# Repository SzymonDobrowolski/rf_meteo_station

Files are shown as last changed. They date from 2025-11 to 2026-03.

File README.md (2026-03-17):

# 🌤️ RF Meteo Station - Custom ESP32 Weather System







A complete, end-to-end open-source weather station project. This system combines custom hardware design, 3D-printed enclosures, and an advanced multithreaded firmware architecture to deliver a modern, touch-enabled weather dashboard.

---

## 1. ⚡ PCB Design (Custom Hardware)
The hardware architecture is divided into two separate custom-designed printed circuit boards:

* **Main Indoor Unit:** Houses the ESP32 microcontroller, power management, display connector (SPI), and the nRF24L01 radio receiver.
* **External Sensor Node:** A low-power, battery-operated board featuring environmental sensors and an nRF24L01 transmitter to send data wirelessly to the main unit.

| Main Board | External Sensor Board |
|:---:|:---:|
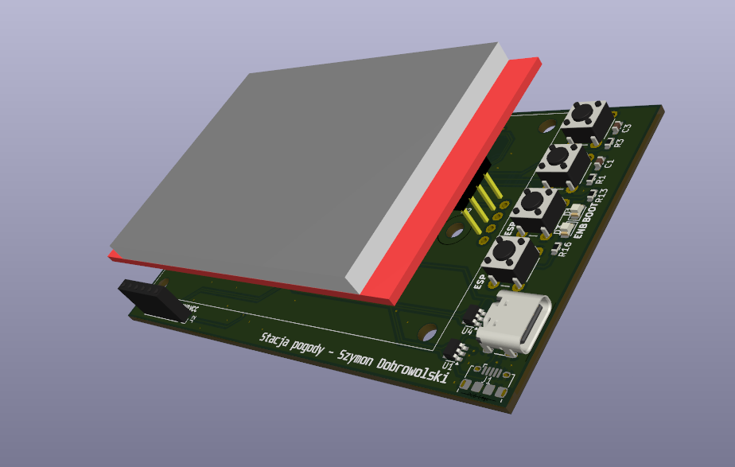
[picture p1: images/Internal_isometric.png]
Main Board PCB
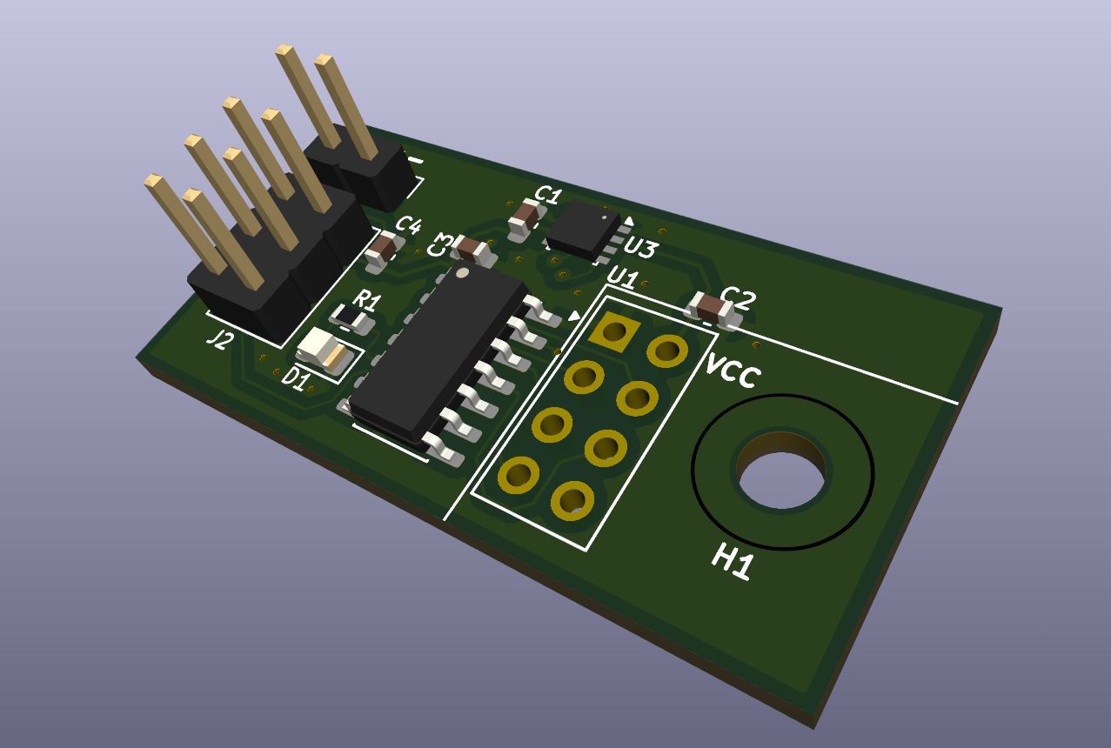
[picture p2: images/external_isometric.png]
Sensor Board PCB
|  |  |

**📄 Full Schematics (PDF):**
* [Open Main Board Schematic PDF](images/int_scheme.pdf)
* [Open Sensor Board Schematic PDF](images/ext_scheme.pdf)

---

## 2. 🧊 Enclosure Design (3D Models)
To make the project a fully finished product, custom enclosures were modeled from scratch and 3D printed.

* **Main Display Case:** Designed to perfectly fit the touch screen, custom PCB, and provide easy access to power ports.
* **Outdoor Sensor Shield:** Features a Stevenson screen-inspired design to protect the external PCB from rain and direct sunlight while allowing accurate temperature and humidity readings.

| Display Enclosure | Sensor Enclosure |
|:---:|:---:|
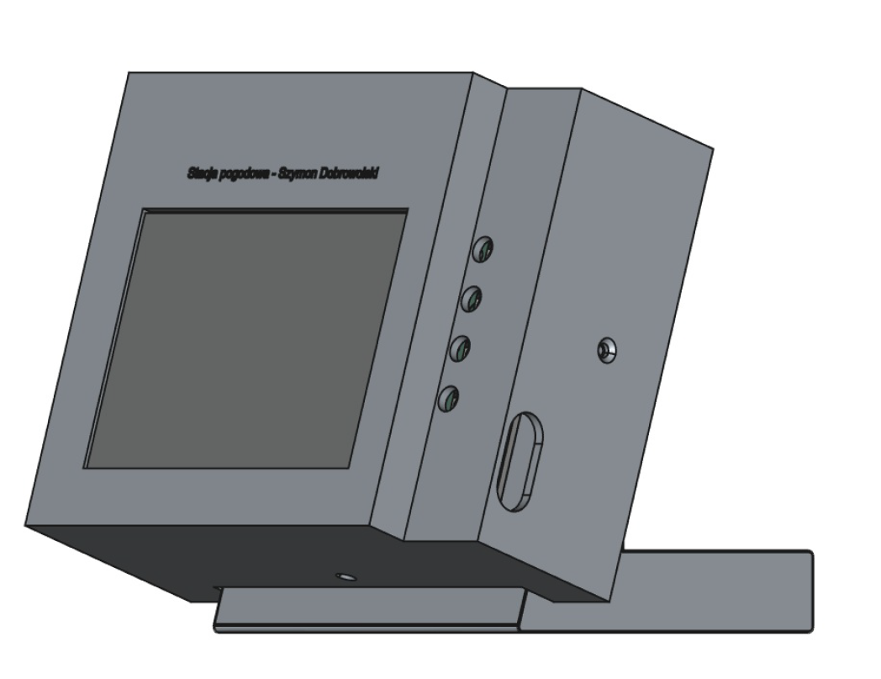
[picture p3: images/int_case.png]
Main Case 3D Model
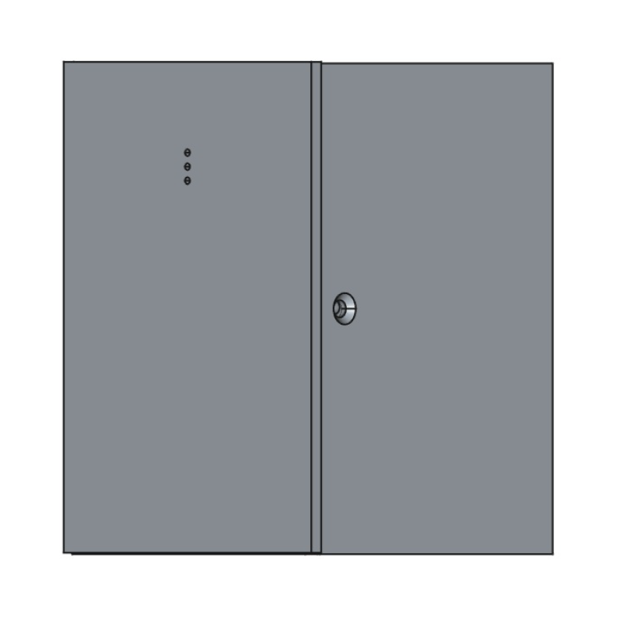
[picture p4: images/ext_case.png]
Sensor Case 3D Model
|  |  |

---

## 3. 💻 Code Architecture & Features
The firmware is built on top of the **ESP-IDF** framework and utilizes **FreeRTOS** to handle multiple background tasks without blocking the UI. 

### Key Software Features:
* **Advanced GUI (LVGL):** A fluid, touch-optimized interface featuring a dashboard, 24h interactive charts, and a 7-day forecast. The UI logic is completely decoupled from the system core.
* **Multithreading:** Dedicated FreeRTOS tasks for display rendering, wireless data receiving (nRF24L01), and Wi-Fi management.
* **Live Weather API:** Fetches and parses real-time forecast data via the Open-Meteo API using `cJSON`.
* **Smart Power Management:** Features a Day/Night mode with a PWM soft-start mechanism to prevent sudden power spikes and brownout resets.
* **NVS Storage:** Safely retains Wi-Fi credentials, location preferences, and brightness settings between reboots.
* **SNTP Time Sync:** Automatically maintains atom-accurate system time in the background.
* **Display Support:** Codebase is optimized for **ST7789** controllers with easy migration to **ILI9341** via the `esp_lcd` framework.

---

## 4. 🚀 How to Build & Flash
The software is designed for the Espressif ESP-IDF framework (v5.0 or newer).

**Step 1: Clone the repository**
```bash
git clone [https://github.com/SzymonDobrowolski/rf_meteo_station.git](https://github.com/SzymonDobrowolski/rf_meteo_station.git)
cd rf_meteo_station/ESP32_int_station_code/internal_module_code_ST7789
```

**Step 2: Install Display Dependencies (ILI9341 Only)**
*Note: The default codebase is optimized for the ST7789 controller. If your specific build uses the ILI9341 display, you must add the official driver component before building:*
```bash
idf.py add-dependency "espressif/esp_lcd_ili9341"
```

**Step 3: Build and Flash**
Connect your ESP32 board and run the following commands:
```bash
idf.py set-target esp32
idf.py build
idf.py -p (YOUR_PORT) flash monitor
```

---

## 5. 🌟 Final Result
Here is the fully assembled, programmed, and working RF Meteo Station in action!

<p align="center">
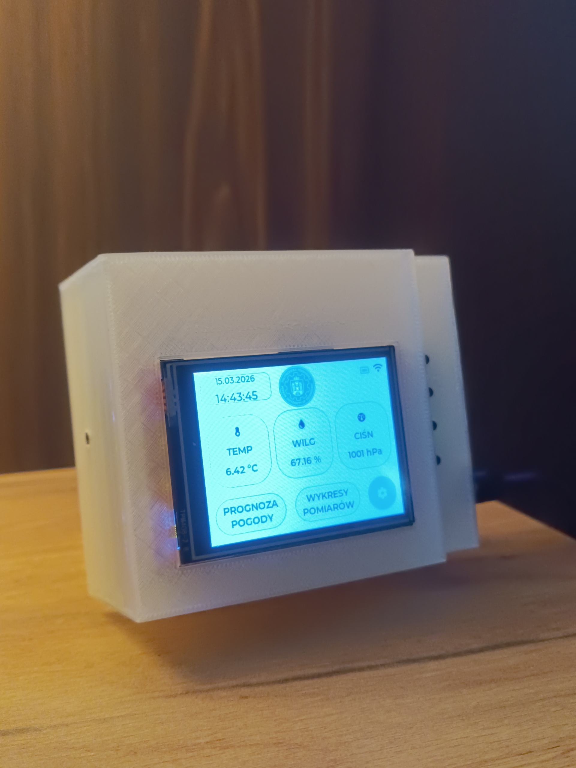
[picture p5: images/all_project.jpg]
Working Station 1
  
  &nbsp;
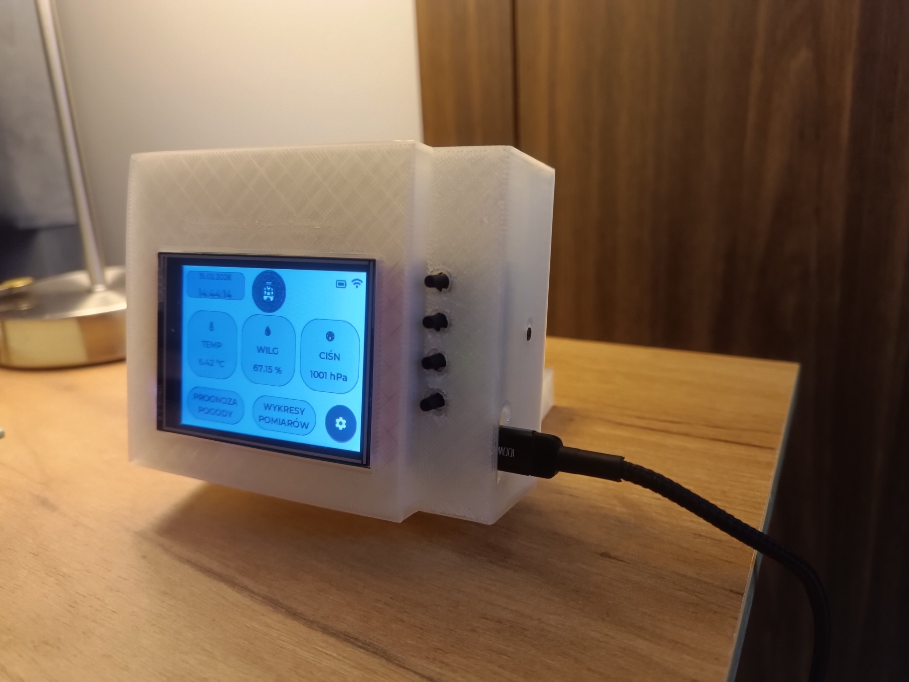
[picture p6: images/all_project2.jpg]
Working Station 2
  
</p>

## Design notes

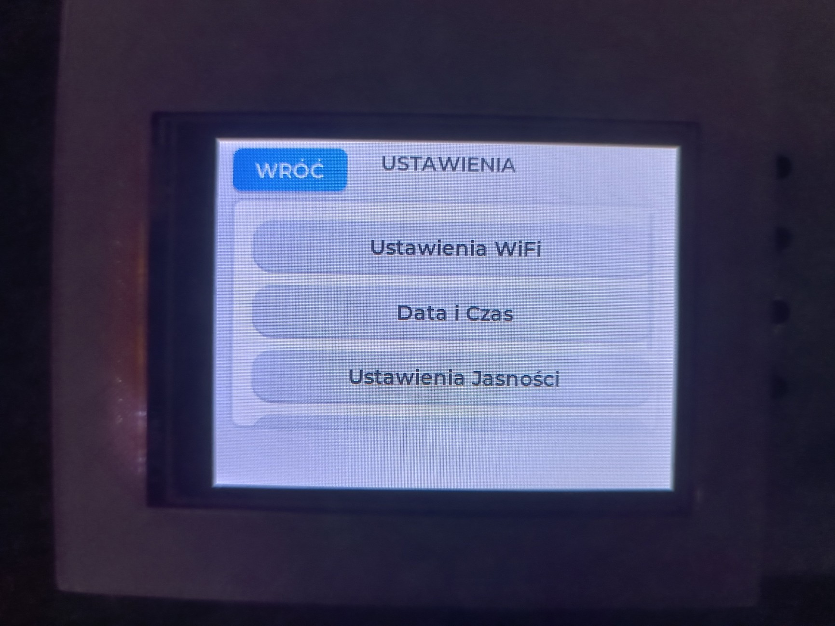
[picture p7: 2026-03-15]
images/settings_screen.jpg

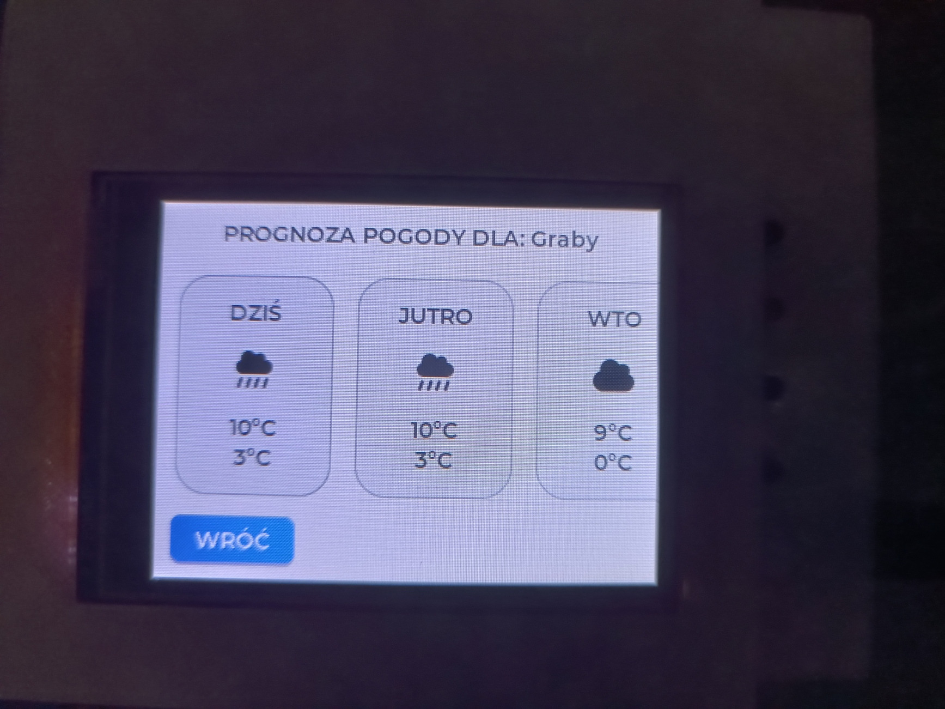
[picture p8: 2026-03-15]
images/weather_info.jpg

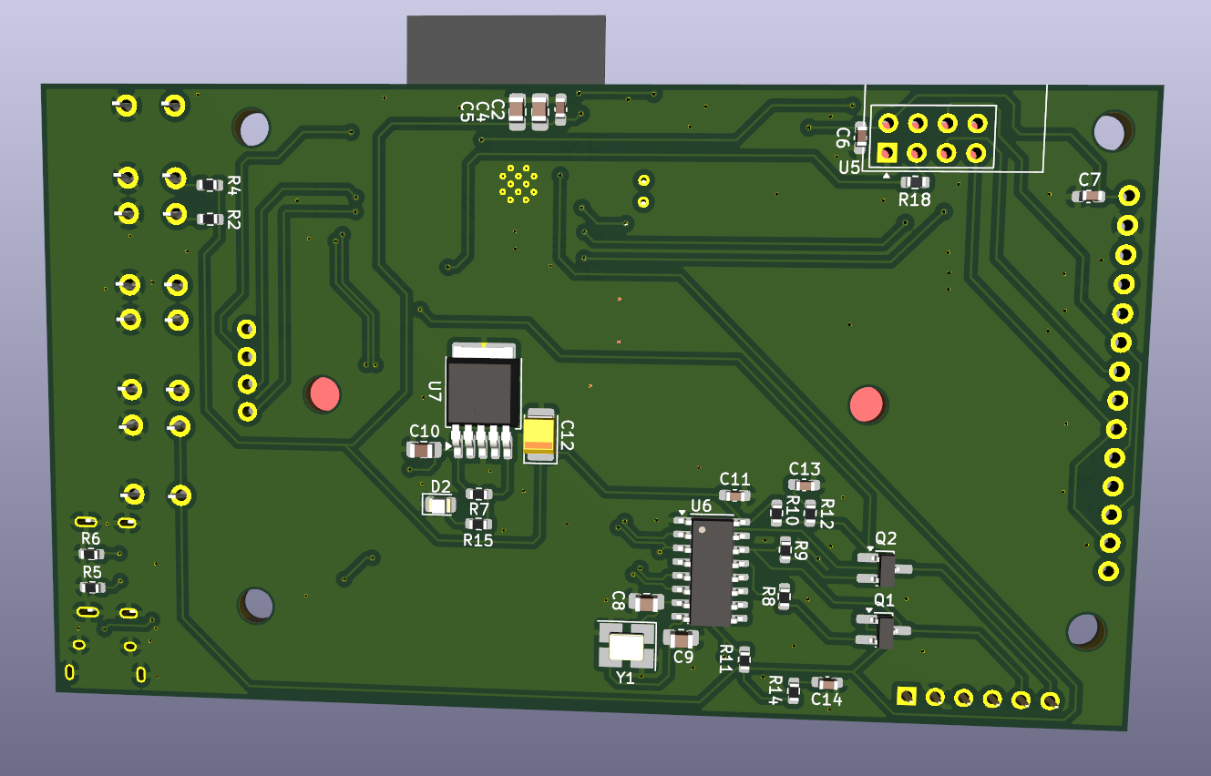
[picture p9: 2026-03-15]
images/Internal_bottom.png

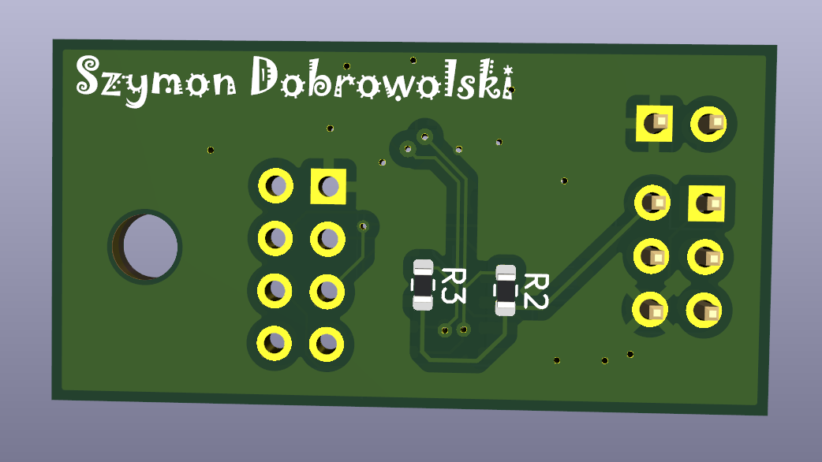
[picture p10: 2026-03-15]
images/external_bottom.png

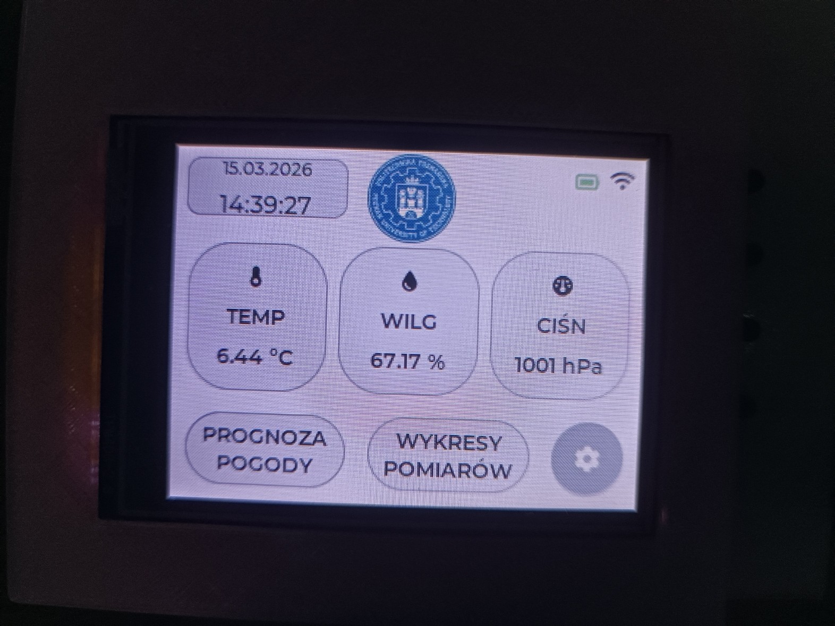
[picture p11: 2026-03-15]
images/main_screen.jpg

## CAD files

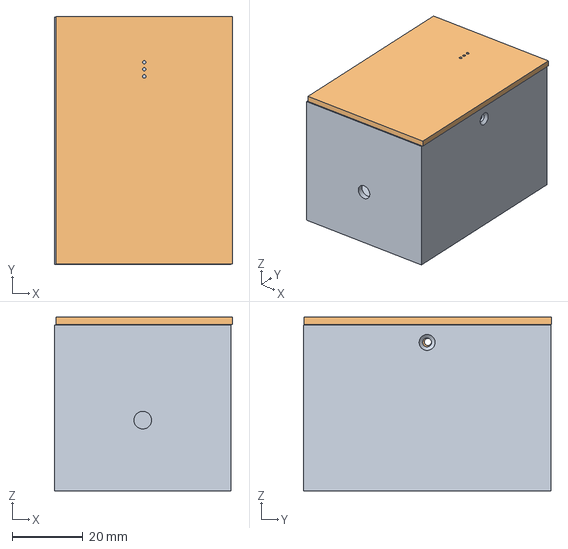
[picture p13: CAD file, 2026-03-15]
ext_station_case/case_ext_merged.FCStd
50.4 x 70.2 x 49.1 mm
Case_ext_001
Case_ext_top_001

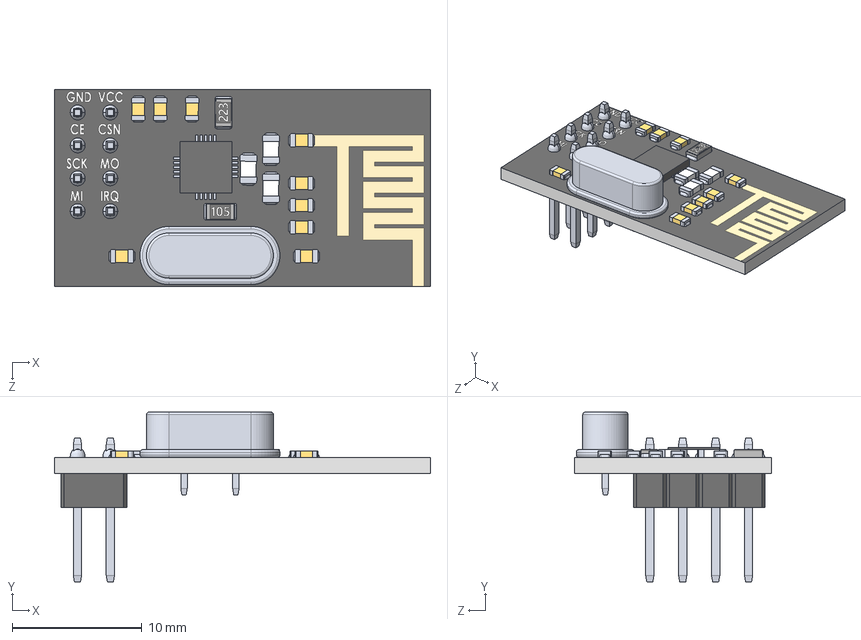
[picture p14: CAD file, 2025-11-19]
ext_station_pcb/wireless-radio-transmitter-and-receiver-nrf24l01-1.snapshot.5/Wireless Radio Transmitter and Receiver nRF24L01.STEP
29.0 x 13.1 x 15.2 mm
nrfboard
CrystalOscillator
doubleMaleHeader x 4
solder x 8
1.7mmSmdCeramicCapacitor x 9
smdResistor223
smdResistor105
smdceramiccapacitorwhite x 3
4x4SMDchip

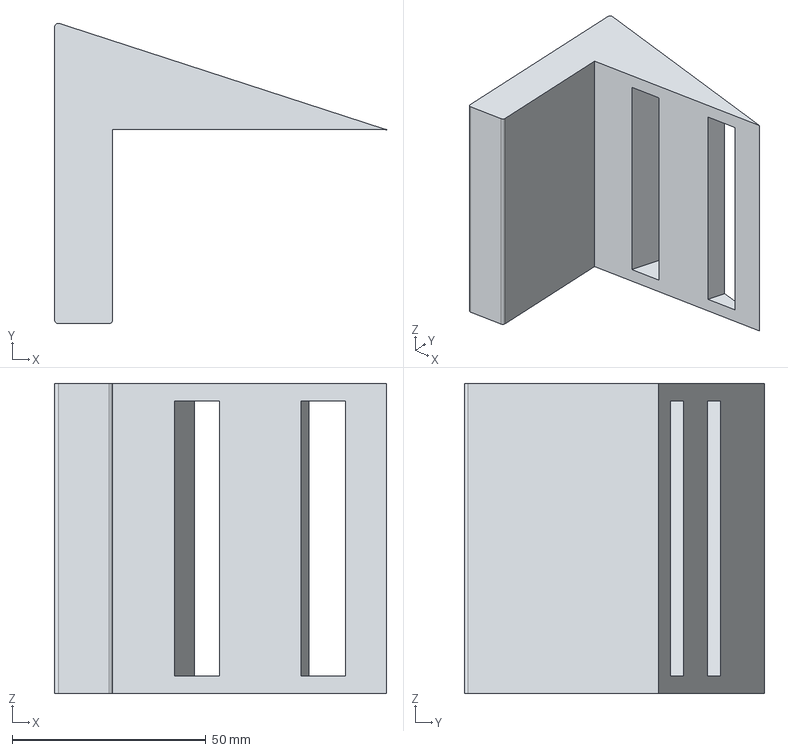
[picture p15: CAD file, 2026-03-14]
int_station_case/Mount-MountPocket002.step
85.6 x 77.4 x 80.0 mm

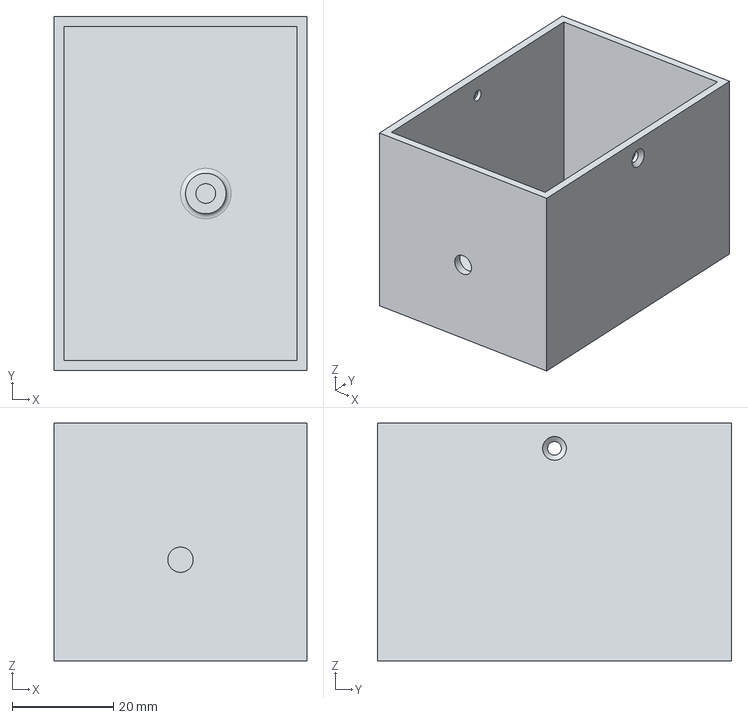
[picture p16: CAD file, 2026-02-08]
ext_station_case/Case_ext.step
50.0 x 70.0 x 47.0 mm

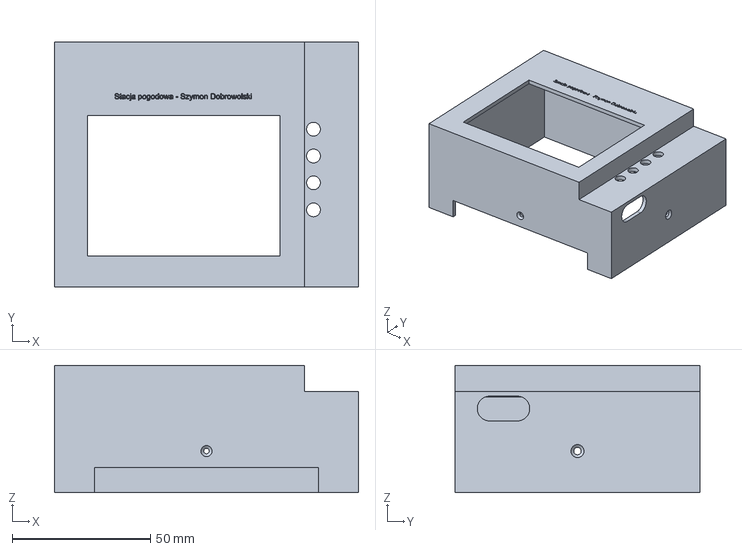
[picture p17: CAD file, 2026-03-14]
int_station_case/Internal_station_top_case.FCStd
110.1 x 88.6 x 46.0 mm

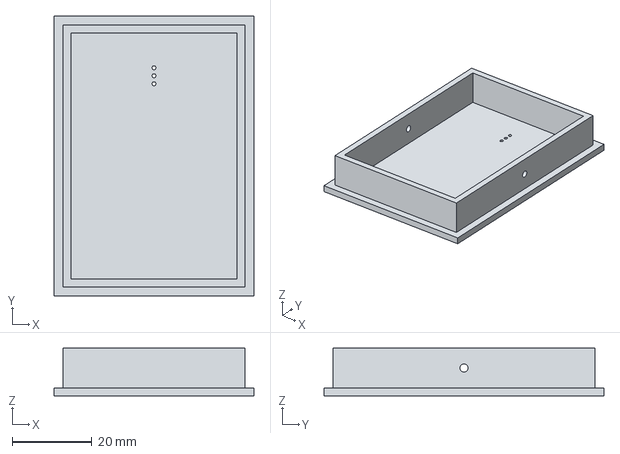
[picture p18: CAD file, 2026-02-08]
ext_station_case/Case_ext_top.step
50.0 x 70.0 x 12.0 mm

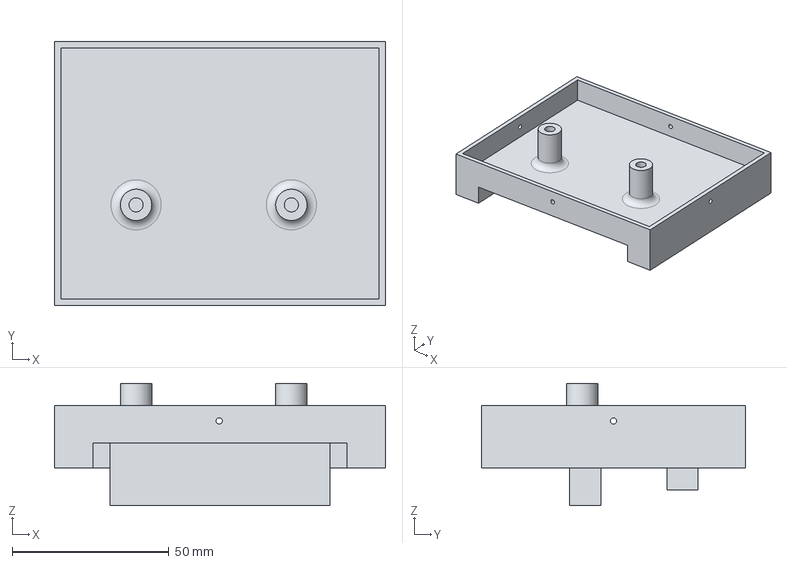
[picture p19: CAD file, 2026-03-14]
int_station_case/Interial_station_bottom_case-BodyHole001.step
105.5 x 84.0 x 39.0 mm

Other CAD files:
int_station_case/Interial_station_bottom_case.FCStd
int_station_case/Mount.FCStd
int_station_case/Internal_station_top_case-BodyHole006.step
ext_station_case/Case_ext.3mf
ext_station_case/Case_ext.FCStd
ext_station_case/Case_ext.stl
ext_station_case/Case_ext_top.3mf
ext_station_case/Case_ext_top.FCStd
ext_station_case/Case_ext_top.stl
ext_station_pcb/wireless-radio-transmitter-and-receiver-nrf24l01-1.snapshot.5/Wireless Radio Transmitter and Receiver nRF24L01.x_t
int_station_case/Interial_station_bottom_case.stl
int_station_case/Internal_station_top_case.stl
int_station_case/Mount.stl

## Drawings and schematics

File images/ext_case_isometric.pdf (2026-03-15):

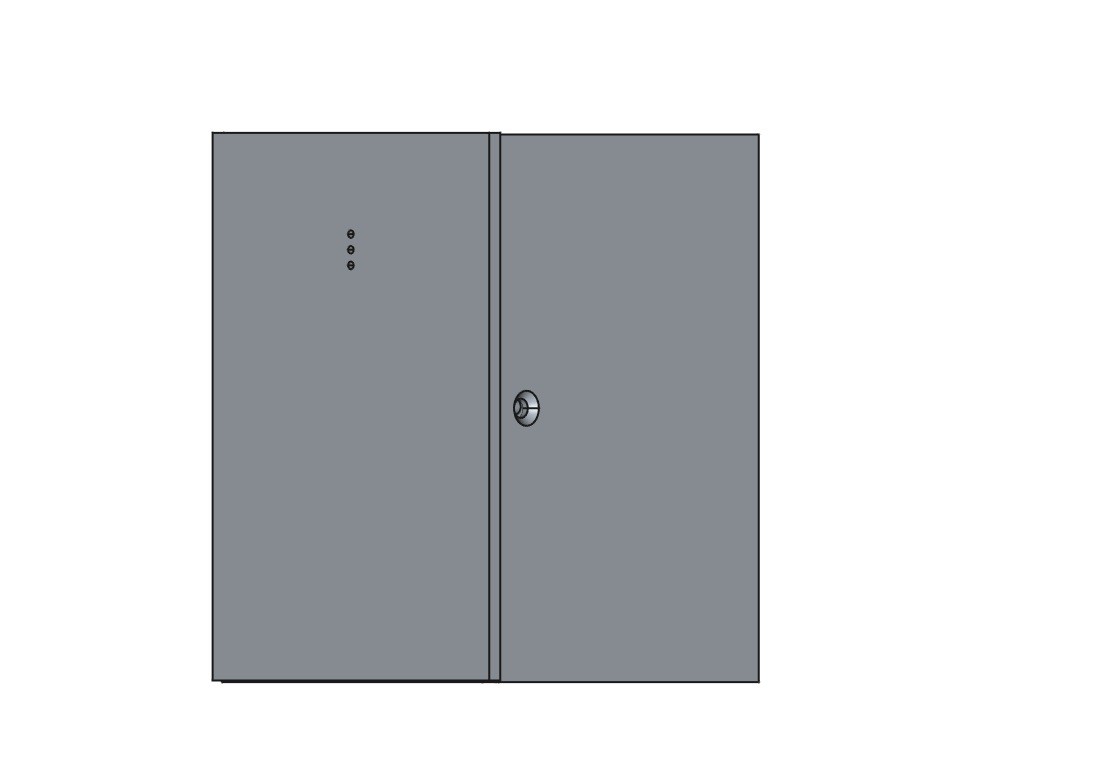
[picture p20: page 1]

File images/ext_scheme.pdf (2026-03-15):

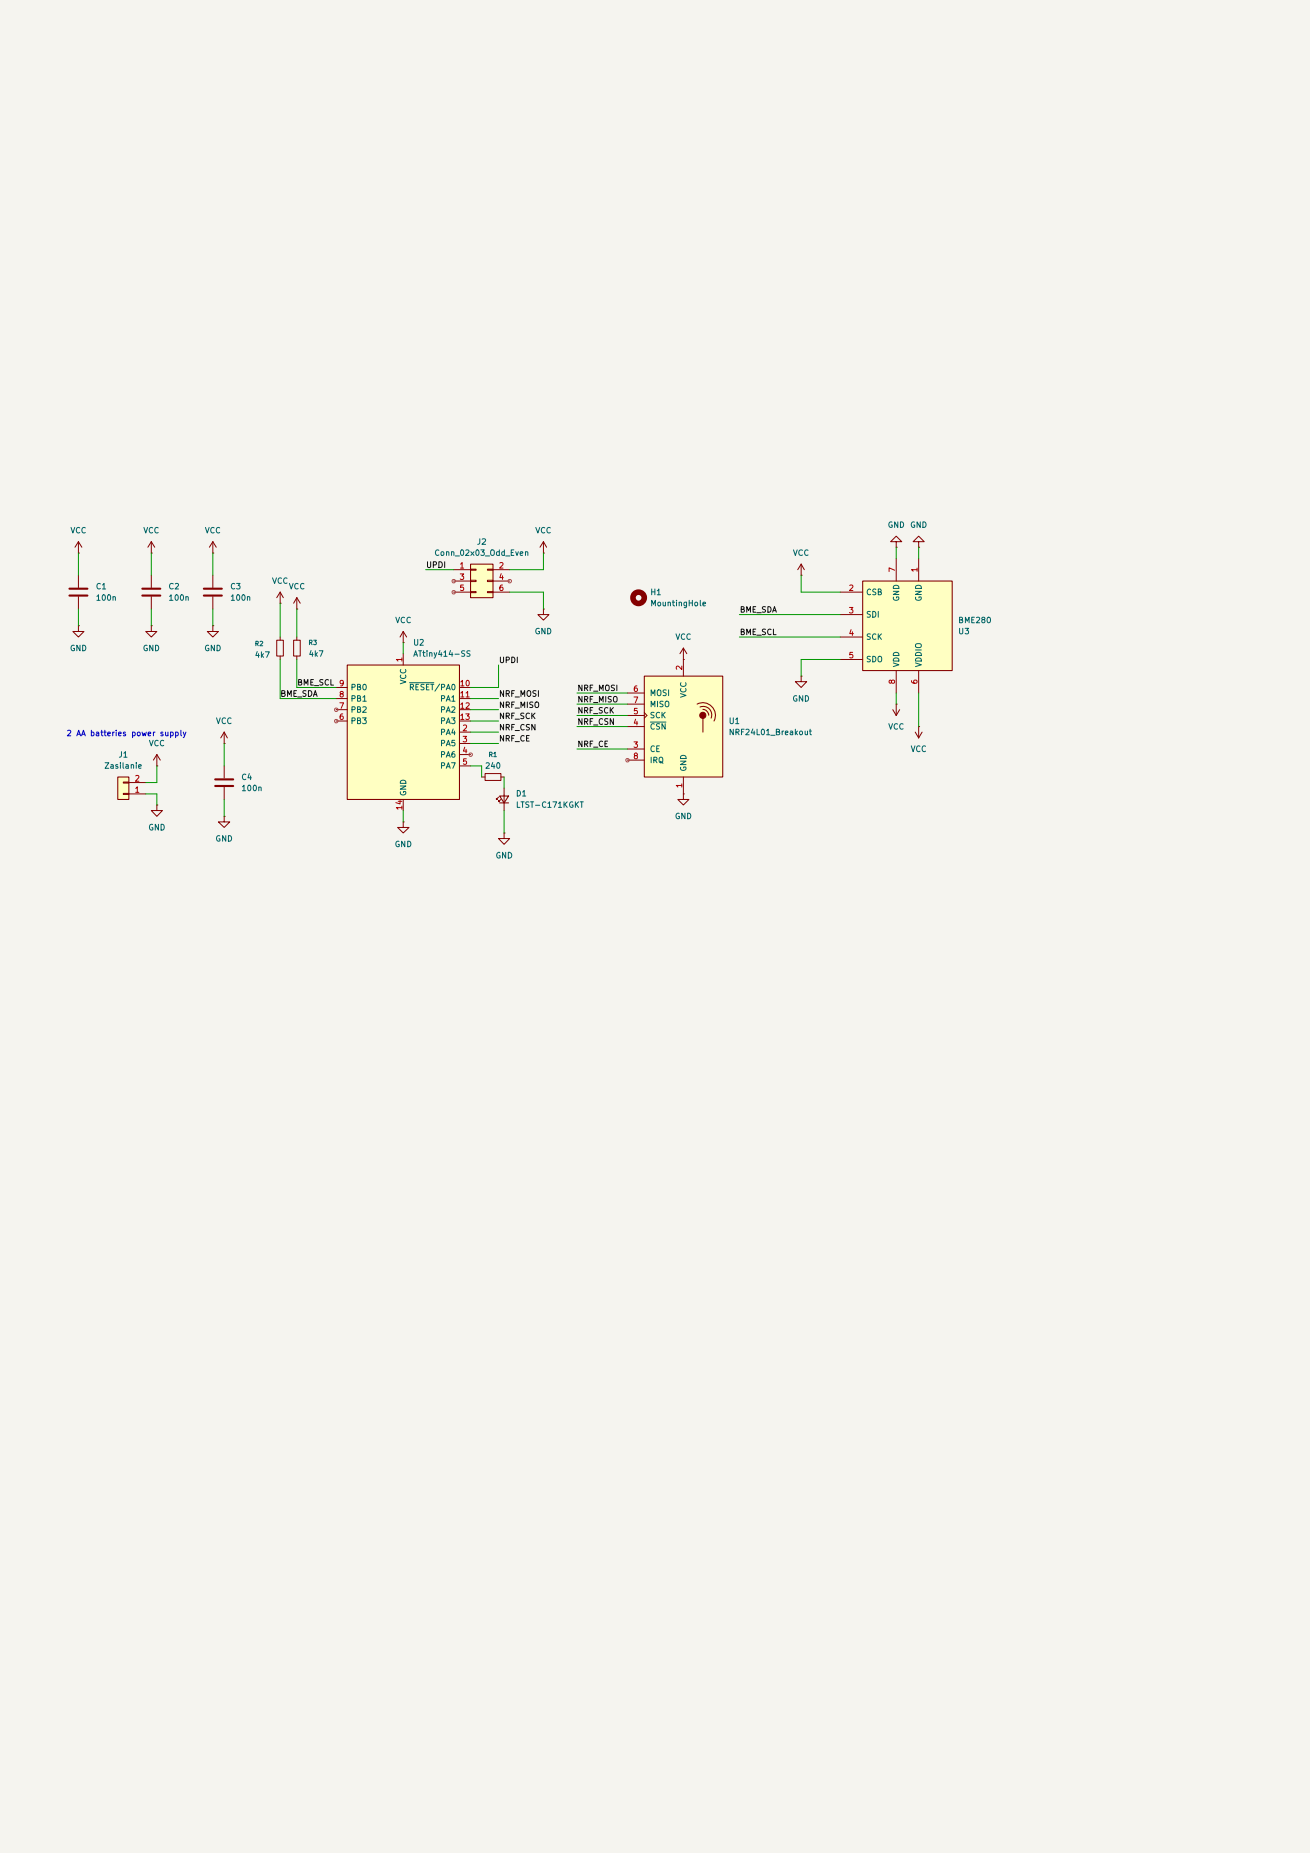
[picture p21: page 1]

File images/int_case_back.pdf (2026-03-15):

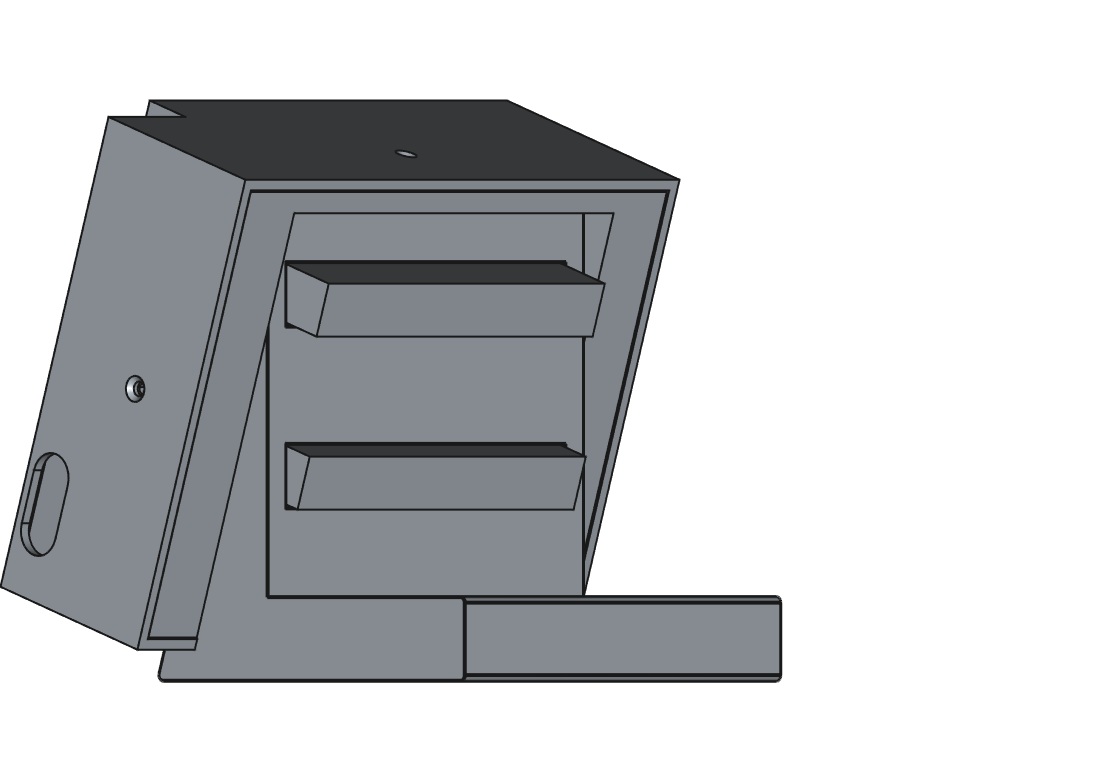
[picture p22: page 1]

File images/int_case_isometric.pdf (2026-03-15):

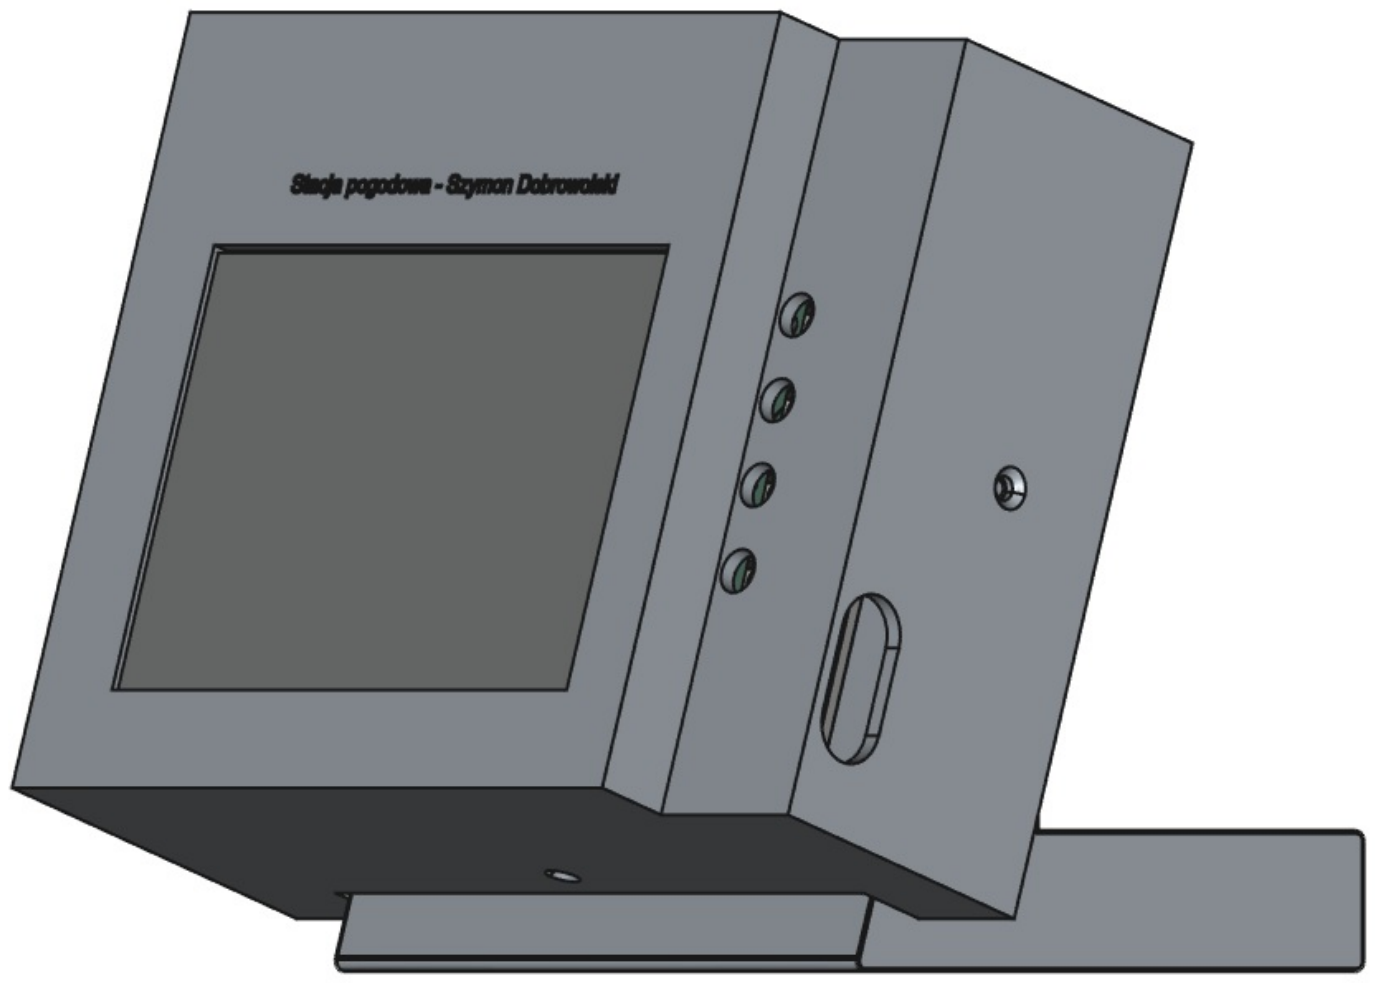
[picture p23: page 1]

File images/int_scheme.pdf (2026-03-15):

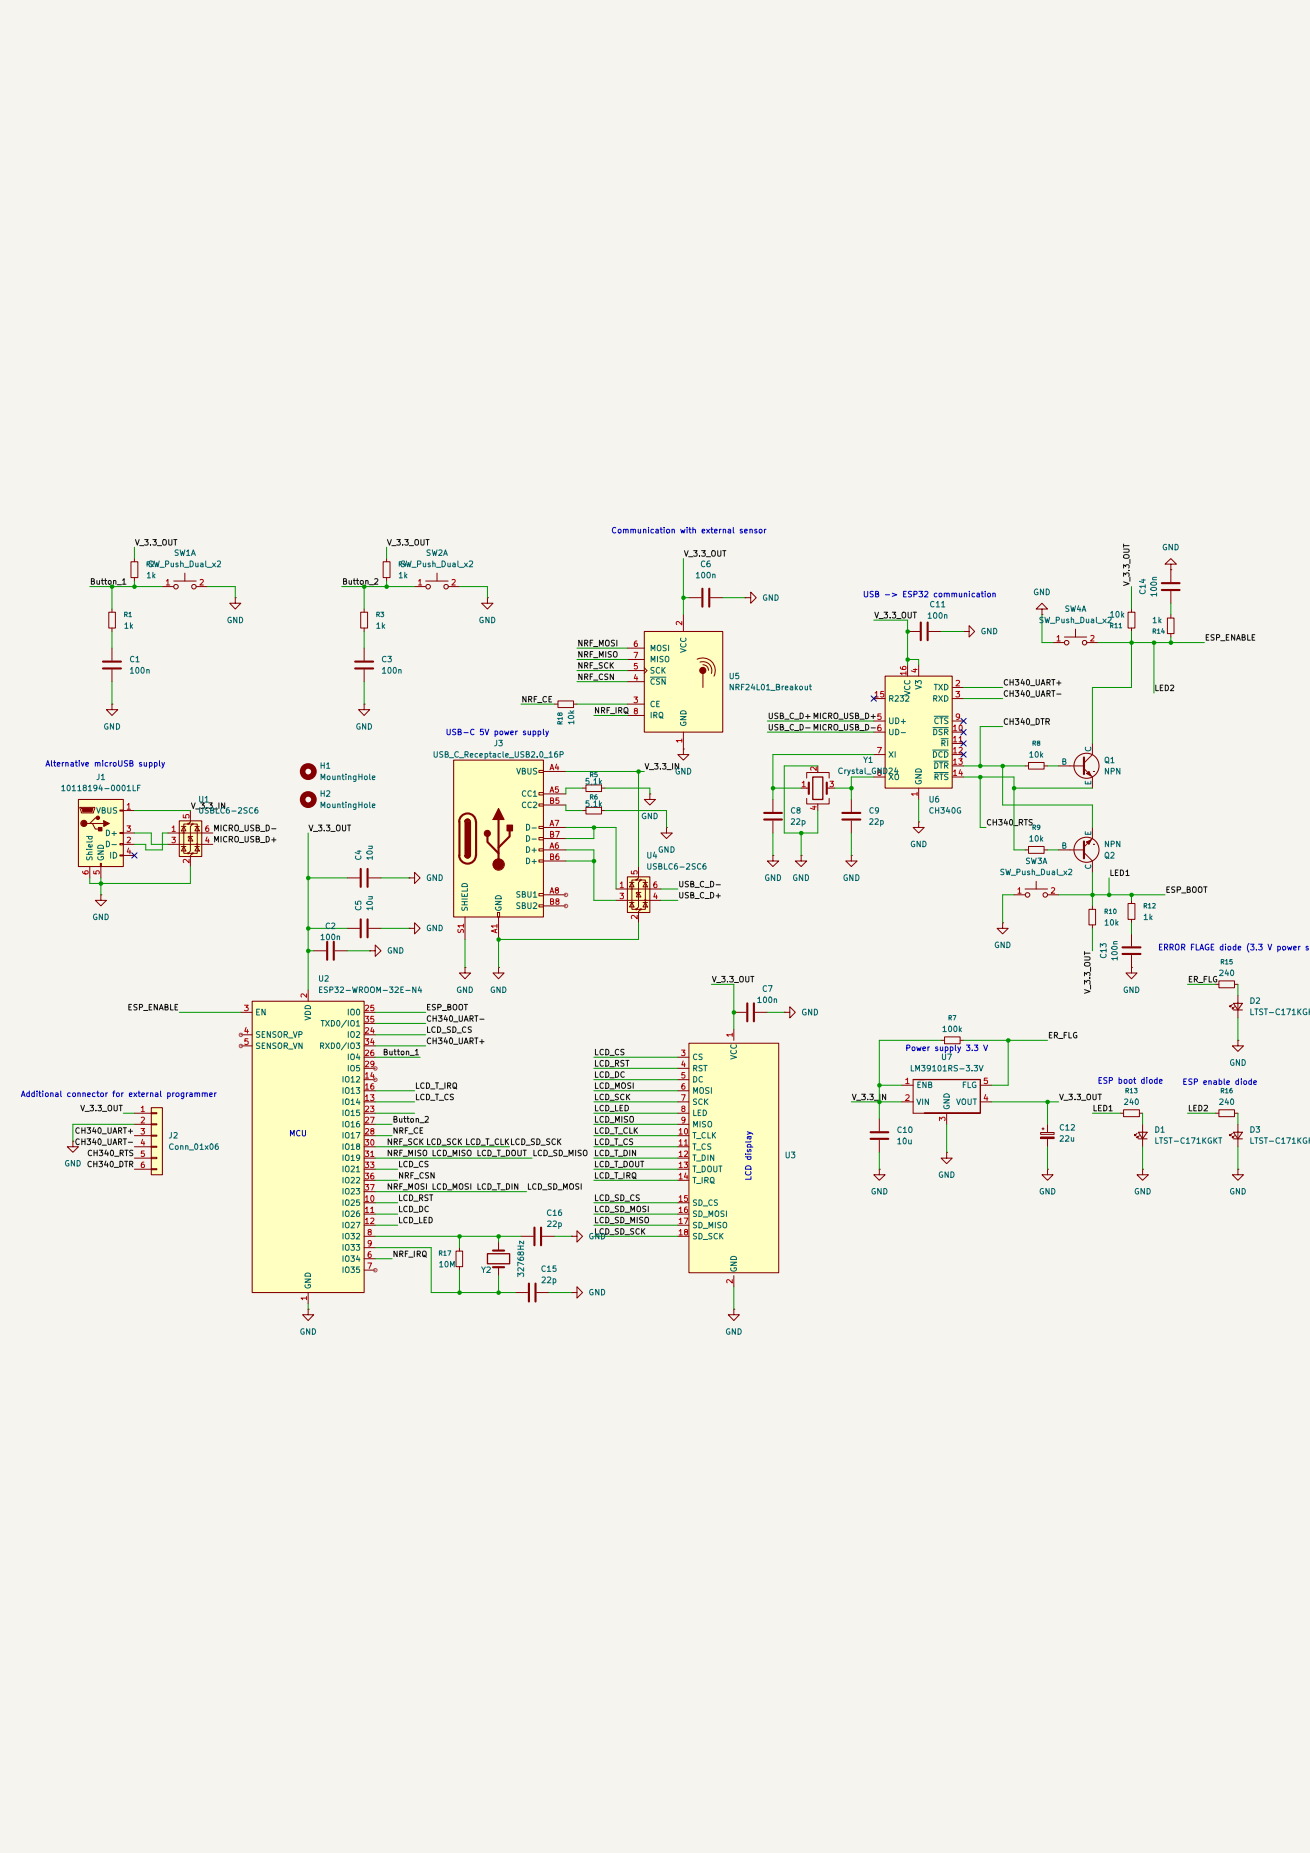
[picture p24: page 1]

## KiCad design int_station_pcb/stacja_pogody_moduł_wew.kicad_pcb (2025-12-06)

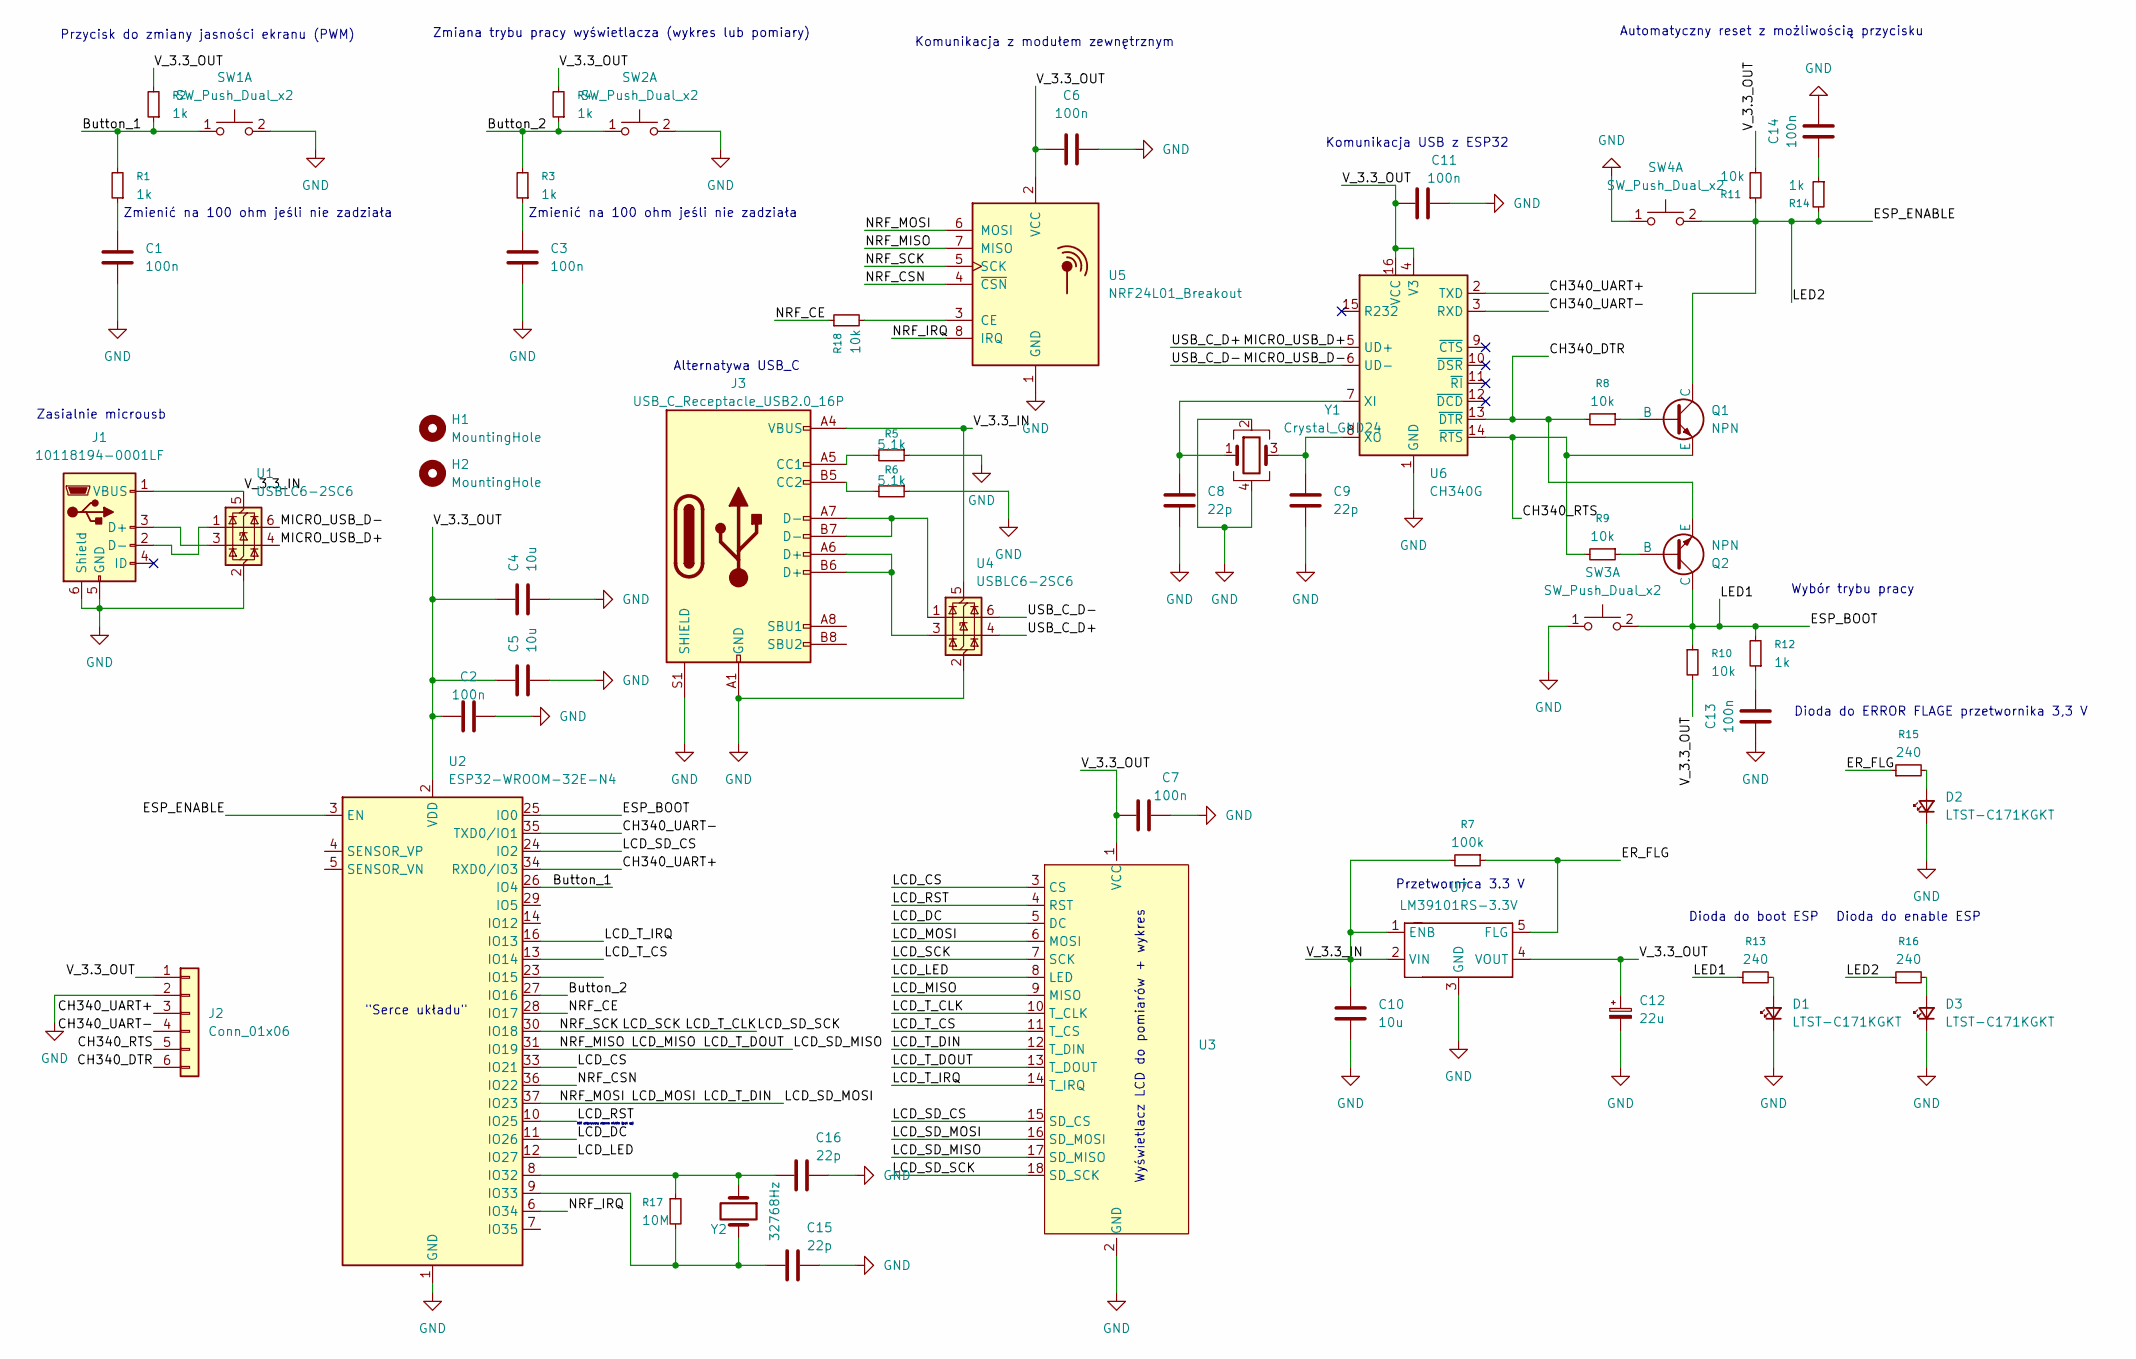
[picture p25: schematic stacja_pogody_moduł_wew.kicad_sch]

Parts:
C1, C2, C3, C6, C7, C11, C13, C14: 100n; C_0603_1608Metric_Pad1.08x0.95mm_HandSolder
C4, C5, C10: 10u; C_0805_2012Metric_Pad1.18x1.45mm_HandSolder
C8, C9: 22p; C_0805_2012Metric_Pad1.18x1.45mm_HandSolder
C12: 22u; CP_EIA-3528-21_Kemet-B_HandSolder
C15, C16: 22p; C_0603_1608Metric_Pad1.08x0.95mm_HandSolder
D1, D2, D3: LTST-C171KGKT; LED_0805_2012Metric
H1, H2: MountingHole; MountingHole_3.2mm_M3
J1: 10118194-0001LF; USB_Micro-B_Amphenol_10118194-0001LF_Horizontal
J2: Conn_01x06; PinSocket_1x06_P2.54mm_Vertical
J3: USB_C_Receptacle_USB2.0_16P; USB_C_Receptacle_TME
Q1, Q2: NPN; SOT-23_Handsoldering
R1, R2, R3, R4, R12, R14: 1k; R_0603_1608Metric
R5, R6: 5,1k; R_0603_1608Metric
R7: 100k; R_0603_1608Metric
R8, R9, R10, R11, R18: 10k; R_0603_1608Metric
R13, R15, R16: 240; R_0603_1608Metric
R17: 10M; R_0603_1608Metric
SW1, SW2, SW3, SW4: SW_Push_Dual_x2; SW_PUSH_6mm_H4.3mm
U1, U4: USBLC6-2SC6; SOT-23-6
U2: ESP32-WROOM-32E-N4; ESP32-WROOM-32E
U3: LCD_2_8
U5: NRF24L01_Breakout; nRF24L01_Breakout
U6: CH340G; SOIC-16_3.9x9.9mm_P1.27mm
U7: LM39101RS-3.3V; TO-252-5_TabPin3
Y1: Crystal_GND24; Crystal_SMD_3225-4Pin_3.2x2.5mm_HandSoldering
Y2: 32768Hz; Crystal_DS26_D2.0mm_L6.0mm_Horizontal

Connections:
/Button_1: R1.2, R2.1, SW1.1 (C), U2.26 (IO4)
/Button_2: R3.2, R4.1, SW2.1 (C), U2.27 (IO16)
/CH340_DTR: J2.6, Q2.3 (E), R8.2, U6.13 (~DTR)
/CH340_RTS: J2.5, Q1.3 (E), R9.2, U6.14 (~RTS)
/CH340_UART+: J2.3, U2.34 (RXD0/IO3), U6.2 (TXD)
/CH340_UART-: J2.4, U2.35 (TXD0/IO1), U6.3 (RXD)
/ER_FLG: R7.1, R15.1, U7.5 (FLG)
/ESP_BOOT: Q2.1 (C), R10.1, R12.2, R13.1, SW3.2 (D), U2.25 (IO0)
/ESP_ENABLE: Q1.1 (C), R11.1, R14.2, R16.1, SW4.2 (D), U2.3 (EN)
/LCD_CS: U2.33 (IO21), U3.3 (CS)
/LCD_DC: U2.11 (IO26), U3.5 (DC)
/LCD_LED: U2.12 (IO27), U3.8 (LED)
/LCD_MISO: U2.31 (IO19), U3.9 (MISO), U3.13 (T_DOUT), U3.17 (SD_MISO), U5.7 (MISO)
/LCD_MOSI: U2.37 (IO23), U3.6 (MOSI), U3.12 (T_DIN), U3.16 (SD_MOSI), U5.6 (MOSI)
/LCD_RST: U2.10 (IO25), U3.4 (RST)
/LCD_SCK: U2.30 (IO18), U3.7 (SCK), U3.10 (T_CLK), U3.18 (SD_SCK), U5.5 (SCK)
/LCD_SD_CS: U2.24 (IO2), U3.15 (SD_CS)
/LCD_T_CS: U2.13 (IO14), U3.11 (T_CS)
/LCD_T_IRQ: U2.16 (IO13), U3.14 (T_IRQ)
/MICRO_USB_D+: U1.4 (I/O2), U4.4 (I/O2), U6.5 (UD+)
/MICRO_USB_D-: U1.6 (I/O1), U4.6 (I/O1), U6.6 (UD-)
/NRF_CE: R18.1, U2.28 (IO17)
/NRF_CSN: U2.36 (IO22), U5.4 (~CSN)
/NRF_IRQ: U2.6 (IO34), U5.8 (IRQ)
/V_3.3_IN: C10.2, J1.1 (VBUS), J3.A4 (VBUS), J3.A9 (VBUS), J3.B4 (VBUS), J3.B9 (VBUS), R7.2, U1.5 (VBUS), U4.5 (VBUS), U7.1 (ENB), U7.2 (VIN)
/V_3.3_OUT: C2.2, C4.2, C5.2, C6.2, C7.2, C11.2, C12.1, J2.1, R2.2, R4.2, R10.2, R11.2, U2.2 (VDD), U3.1 (VCC), U5.2 (VCC), U6.4 (V3), U6.16 (VCC), U7.4 (VOUT)
GND: C1.1, C2.1, C3.1, C4.1, C5.1, C6.1, C7.1, C8.2, C9.2, C10.1, C11.1, C12.2, C13.2, C14.2, C15.1, C16.1, D1.1 (K), D2.1 (K), D3.1 (K), J1.5 (GND), J1.6 (Shield), J2.2, J3.A1 (GND), J3.A12 (GND), J3.B1 (GND), J3.B12 (GND), J3.S1 (SHIELD), R5.1, R6.1, SW1.2 (D), SW2.2 (D), SW3.1 (C), SW4.1 (C), U1.2 (GND), U2.1 (GND), U2.15 (GND), U2.38 (GND), U2.39 (GND), U3.2 (GND), U4.2 (GND), U5.1 (GND), U6.1 (GND), U7.3 (GND), Y1.2, Y1.4
unnamed: C1.2, R1.1
unnamed: C3.2, R3.1
unnamed: C13.1, R12.1
unnamed: C14.1, R14.1
unnamed: D1.2 (A), R13.2
unnamed: D2.2 (A), R15.2
unnamed: D3.2 (A), R16.2
unnamed: J1.3 (D+), U1.3 (I/O2)
unnamed: J1.2 (D-), U1.1 (I/O1)
unnamed: J3.A5 (CC1), R5.2
unnamed: J3.B5 (CC2), R6.2
unnamed: J3.A6 (D+), J3.B6 (D+), U4.3 (I/O2)
unnamed: J3.A7 (D-), J3.B7 (D-), U4.1 (I/O1)
unnamed: Q1.2 (B), R8.1
unnamed: Q2.2 (B), R9.1
unnamed: C16.2, R17.1, U2.8 (IO32), Y2.1
unnamed: C15.2, R17.2, U2.9 (IO33), Y2.2
unnamed: R18.2, U5.3 (CE)
unnamed: C8.1, U6.7 (XI), Y1.1
unnamed: C9.1, U6.8 (XO), Y1.3

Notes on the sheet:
Wyświetlacz LCD do pomiarów + wykres
Komunikacja z modułem zewnętrznym
Zmienić na 100 ohm jeśli nie zadziała
Zasialnie microusb
Wybór trybu pracy
Dioda do enable ESP
Automatyczny reset z możliwością przycisku
Dioda do boot ESP
RST aktywowany stanem niskim (pull up)
Alternatywa USB_C
Dioda do ERROR FLAGE przetwornika 3,3 V
Komunikacja USB z ESP32
Zmiana trybu pracy wyświetlacza (wykres lub pomiary)
Przycisk do zmiany jasności ekranu (PWM)
"Serce układu"
Przetwornica 3.3 V

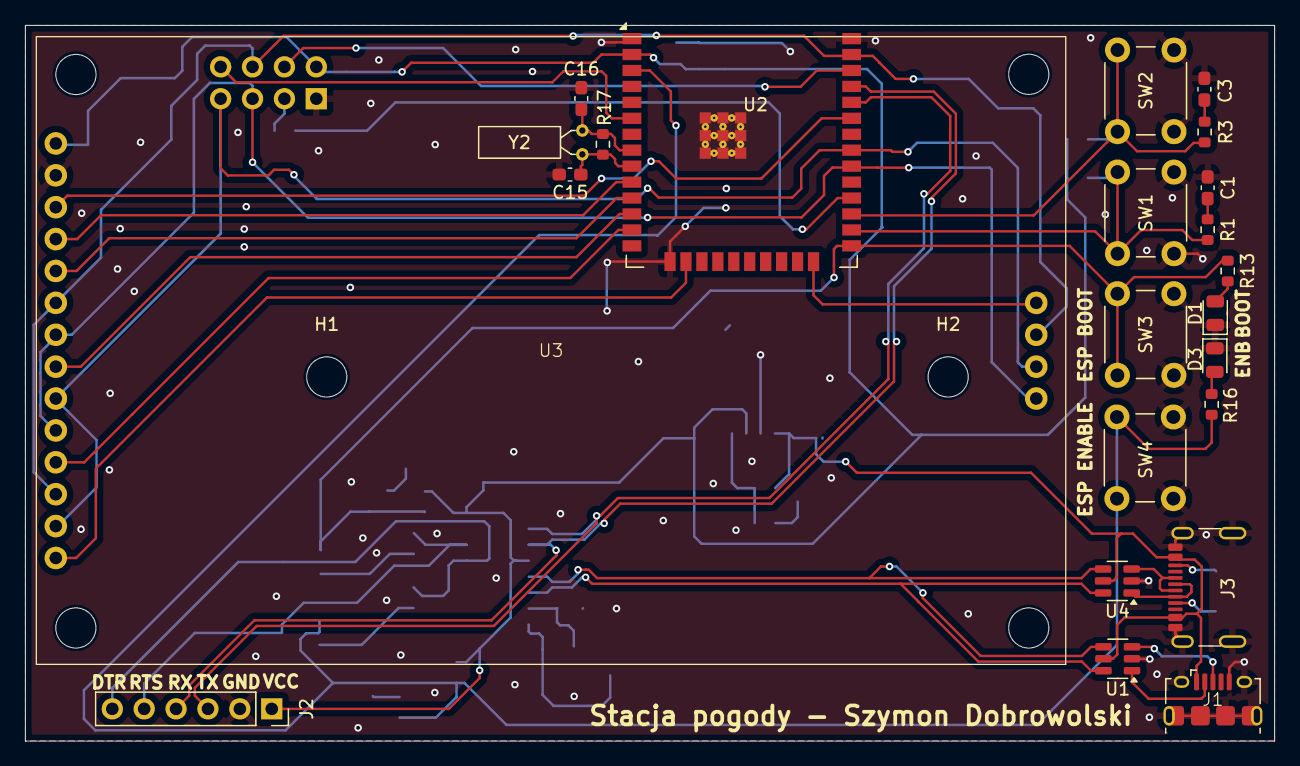
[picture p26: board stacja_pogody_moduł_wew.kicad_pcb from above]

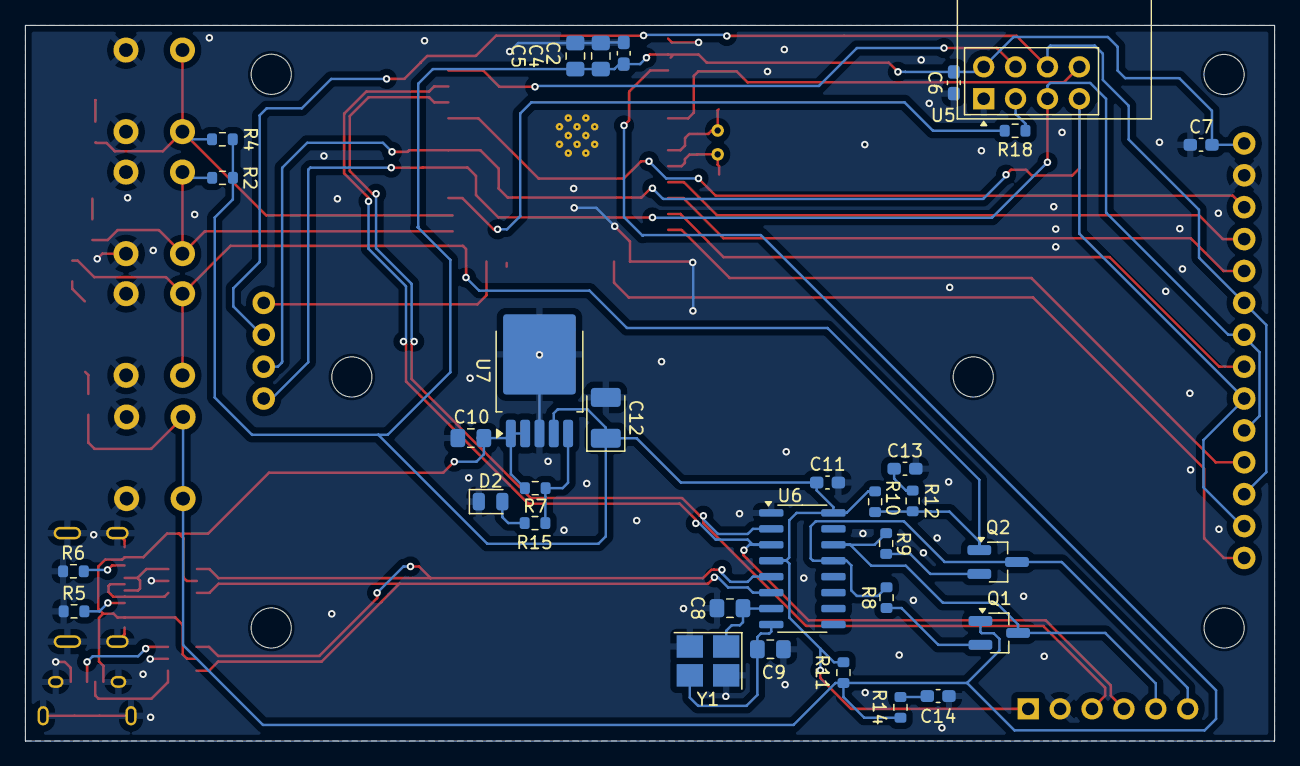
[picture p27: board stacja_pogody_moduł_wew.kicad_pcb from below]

Board: 2 copper layers, 99.5 x 57.0 mm, 57 parts (32 on the bottom side), 47 nets.

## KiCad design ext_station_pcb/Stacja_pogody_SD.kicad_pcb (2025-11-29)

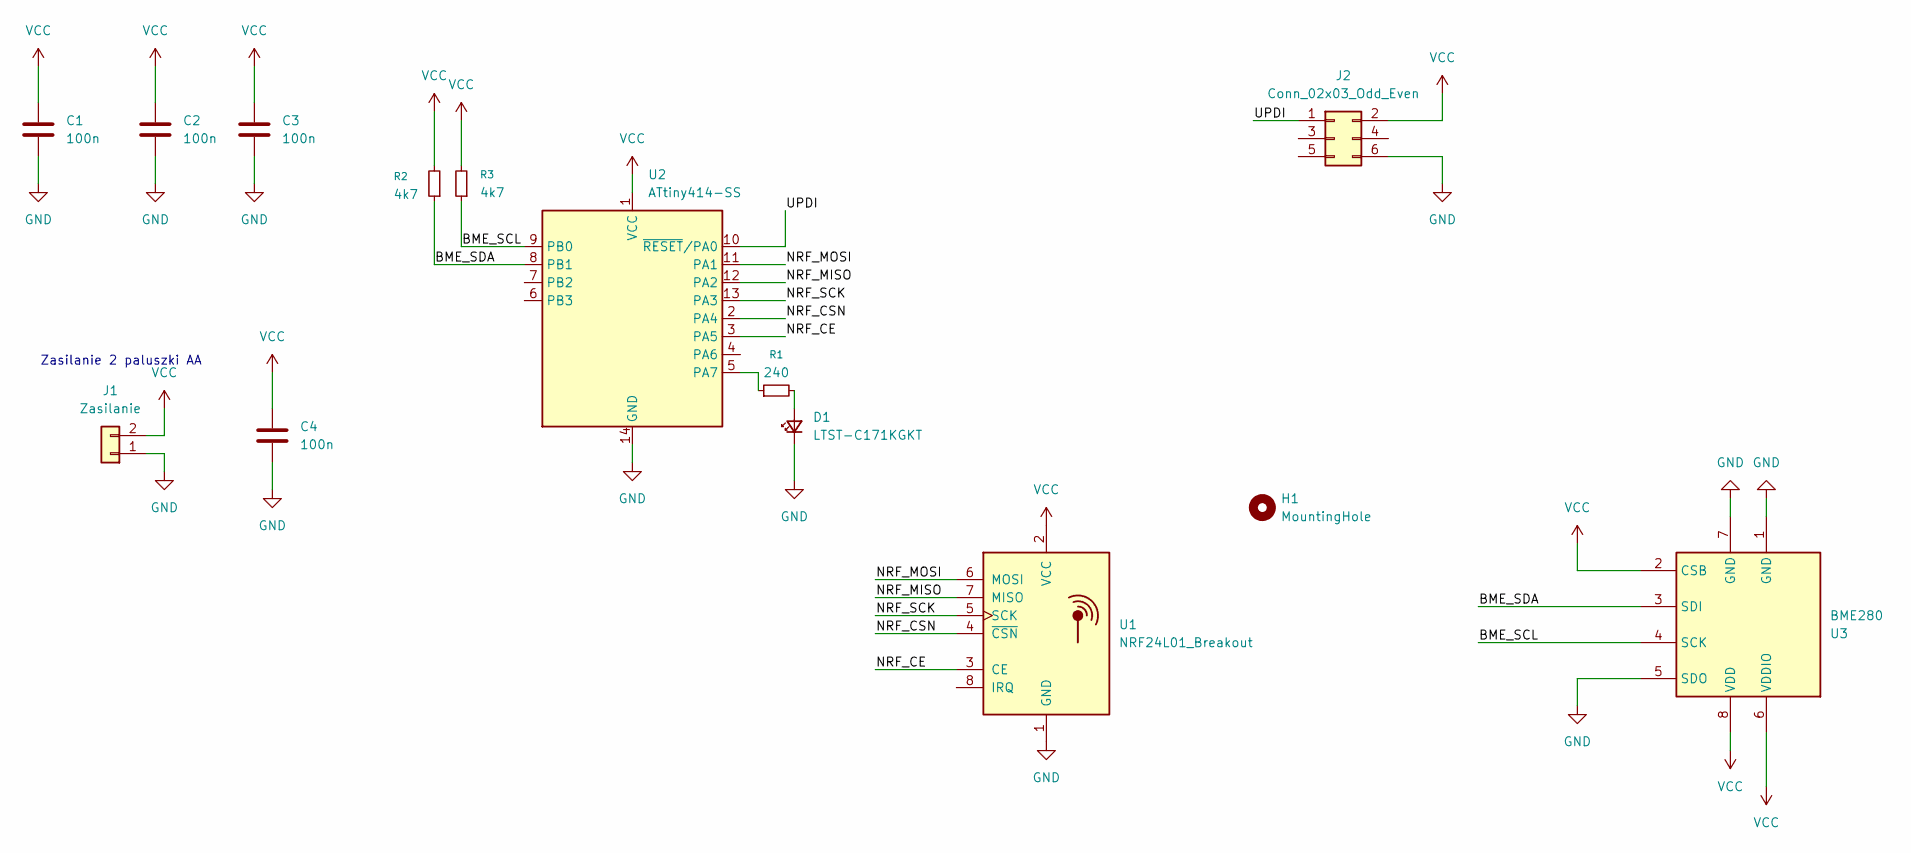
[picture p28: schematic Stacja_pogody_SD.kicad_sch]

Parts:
C1, C2, C3, C4: 100n; C_0603_1608Metric
D1: LTST-C171KGKT; LED_0805_2012Metric
H1: MountingHole; MountingHole_3.2mm_M3
J1: Zasilanie; PinHeader_1x02_P2.54mm_Vertical
J2: Conn_02x03_Odd_Even; PinHeader_2x03_P2.54mm_Vertical
R1: 240; R_0603_1608Metric
R2, R3: 4k7; R_0603_1608Metric
U1: NRF24L01_Breakout; nRF24L01_Breakout
U2: ATtiny414-SS; SOIC-14_3.9x8.7mm_P1.27mm
U3: BME280; Bosch_LGA-8_2.5x2.5mm_P0.65mm_ClockwisePinNumbering

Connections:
/BME_SCL: R3.1, U2.9 (PB0), U3.4 (SCK)
/BME_SDA: R2.1, U2.8 (PB1), U3.3 (SDI)
/NRF_CE: U1.3 (CE), U2.3 (PA5)
/NRF_CSN: U1.4 (~CSN), U2.2 (PA4)
/NRF_MISO: U1.7 (MISO), U2.12 (PA2)
/NRF_MOSI: U1.6 (MOSI), U2.11 (PA1)
/NRF_SCK: U1.5 (SCK), U2.13 (PA3)
/UPDI: J2.1, U2.10 (~RESET/PA0)
GND: C1.1, C2.1, C3.1, C4.1, D1.1 (K), J1.1, J2.6, U1.1 (GND), U2.14 (GND), U3.1 (GND), U3.5 (SDO), U3.7 (GND)
unnamed: D1.2 (A), R1.2
unnamed: R1.1, U2.5 (PA7)
VCC: C1.2, C2.2, C3.2, C4.2, J1.2, J2.2, R2.2, R3.2, U1.2 (VCC), U2.1 (VCC), U3.2 (CSB), U3.6 (VDDIO), U3.8 (VDD)

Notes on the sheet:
Zasilanie 2 paluszki AA

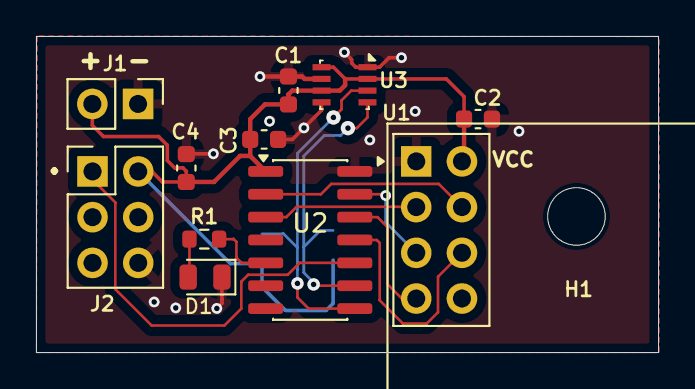
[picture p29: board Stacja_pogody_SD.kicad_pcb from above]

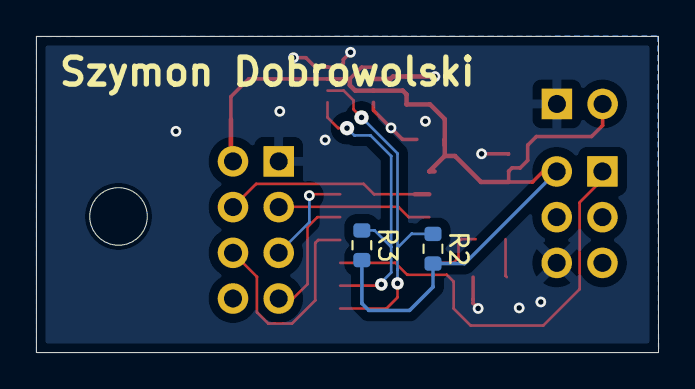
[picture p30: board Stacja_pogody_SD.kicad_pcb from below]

Board: 2 copper layers, 34.6 x 17.6 mm, 14 parts (2 on the bottom side), 12 nets.

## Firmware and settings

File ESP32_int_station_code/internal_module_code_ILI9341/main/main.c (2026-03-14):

#include <stdio.h>
#include <string.h>
#include <time.h>
#include <sys/time.h>
#include "freertos/FreeRTOS.h"
#include "freertos/task.h"
#include "freertos/semphr.h"
#include "freertos/queue.h"
#include "esp_log.h"
#include "driver/ledc.h"
#include "nvs_flash.h"
#include "esp_wifi.h"
#include "esp_http_client.h"
#include "cJSON.h"
#include "nvs.h"

// LVGL
#include "lvgl.h"
#include "esp_lvgl_port.h"

// Moduły sprzętowe i projektowe
#include "gpio_init.h"
#include "spi_init.h"
#include "nrf.h"
#include "wifi_project.h"
#include "sntp.h"
#include "lcd.h"
#include "Config.h"
#include "touch.h"

// Nasz nowy moduł interfejsu graficznego!
#include "ui.h" 

static const char *TAG = "MAIN";

// --- MAKRA IKON POGODOWYCH (Dla fetch_weather_task) ---
#define SYM_W_SUN        "\xEF\x86\x85" 
#define SYM_W_CLOUD      "\xEF\x83\x82" 
#define SYM_W_CLOUD_SUN  "\xEF\x9B\x84" 
#define SYM_W_RAIN       "\xEF\x9D\x80" 
#define SYM_W_SNOW       "\xEF\x8B\x9C" 
#define SYM_W_STORM      "\xEF\x83\xA7" 

// --- ZMIENNE GLOBALNE SYSTEMOWE ---
spi_device_handle_t nrf_handle = NULL;
SemaphoreHandle_t xSpiMutex = NULL;
QueueHandle_t xSensorQueue = NULL;

char current_city[64] = "Warszawa"; 
bool force_weather_update = true;   
uint32_t day_brightness = 100; 
uint32_t night_brightness = 25; 
bool is_wifi_connecting = false;


// ==========================================================
// 1. INICJALIZACJA SPRZĘTU (PWM)
// ==========================================================
void backlight_pwm_init(void) {
    ledc_timer_config_t ledc_timer = {
        .speed_mode       = LEDC_LOW_SPEED_MODE,
        .timer_num        = LEDC_TIMER_0,
        .duty_resolution  = LEDC_TIMER_8_BIT, 
        .freq_hz          = 5000,             
        .clk_cfg          = LEDC_AUTO_CLK
    };
    ESP_ERROR_CHECK(ledc_timer_config(&ledc_timer));

    ledc_channel_config_t ledc_channel = {
        .speed_mode     = LEDC_LOW_SPEED_MODE,
        .channel        = LEDC_CHANNEL_0,
        .timer_sel      = LEDC_TIMER_0,
        .intr_type      = LEDC_INTR_DISABLE,
        .gpio_num       = BL_PIN,
        .duty           = 255,  // Rozruch bezpieczny
        .hpoint         = 0
    };
    ESP_ERROR_CHECK(ledc_channel_config(&ledc_channel));
}

// ==========================================================
// 2. FUNKCJE PAMIĘCI NVS (Zapis i odczyt ustawień)
// ==========================================================
void save_brightness_settings(uint32_t day, uint32_t night) {
    nvs_handle_t my_handle;
    if (nvs_open("storage", NVS_READWRITE, &my_handle) == ESP_OK) {
        nvs_set_u32(my_handle, "day_br", day);
        nvs_set_u32(my_handle, "night_br", night);
        nvs_commit(my_handle);
        nvs_close(my_handle);
    }
}

void load_brightness_settings(void) {
    nvs_handle_t my_handle;
    if (nvs_open("storage", NVS_READONLY, &my_handle) == ESP_OK) {
        nvs_get_u32(my_handle, "day_br", &day_brightness);
        nvs_get_u32(my_handle, "night_br", &night_brightness);
        nvs_close(my_handle);
    }
}

void save_location_settings(const char * city) {
    nvs_handle_t my_handle;
    if (nvs_open("storage", NVS_READWRITE, &my_handle) == ESP_OK) {
        nvs_set_str(my_handle, "city", city);
        nvs_commit(my_handle);
        nvs_close(my_handle);
        ESP_LOGI(TAG, "Zapisano miasto: %s", city);
    }
}

void load_location_settings(void) {
    nvs_handle_t my_handle;
    if (nvs_open("storage", NVS_READONLY, &my_handle) == ESP_OK) {
        size_t len = sizeof(current_city);
        nvs_get_str(my_handle, "city", current_city, &len);
        nvs_close(my_handle);
    }
}

void save_wifi_credentials(const char * ssid, const char * pass) {
    nvs_handle_t my_handle;
    if (nvs_open("storage", NVS_READWRITE, &my_handle) == ESP_OK) {
        nvs_set_str(my_handle, "ssid", ssid);
        nvs_set_str(my_handle, "pass", pass);
        nvs_commit(my_handle);
        nvs_close(my_handle);
        ESP_LOGI(TAG, "Zapisano dane WiFi do NVS: %s", ssid);
    }
}

bool load_wifi_credentials(char * ssid, char * pass, size_t max_len) {
    nvs_handle_t my_handle;
    if (nvs_open("storage", NVS_READONLY, &my_handle) == ESP_OK) {
        size_t len = max_len;
        esp_err_t err_ssid = nvs_get_str(my_handle, "ssid", ssid, &len);
        len = max_len;
        esp_err_t err_pass = nvs_get_str(my_handle, "pass", pass, &len);
        nvs_close(my_handle);
        return (err_ssid == ESP_OK && err_pass == ESP_OK);
    }
    return false;
}

// ==========================================================
// 3. FUNKCJE POMOCNICZE (Logika)
// ==========================================================
uint8_t get_battery_level(uint16_t v) {
    if (v >= 3000) return 100;
    if (v <= 2000) return 0;
    if (v > 2800) return 85 + 15 * (v - 2800) / 200; 
    else if (v > 2400) return 30 + 55 * (v - 2400) / 400;
    else if (v > 2200) return 10 + 20 * (v - 2200) / 200;
    else return 10 * (v - 2000) / 200;
}

const char* get_weather_icon(int code) {
    if (code == 0 || code == 1) return SYM_W_SUN; 
    if (code == 2) return SYM_W_CLOUD_SUN; 
    if (code == 3 || code == 45 || code == 48) return SYM_W_CLOUD; 
    if ((code >= 51 && code <= 67) || (code >= 80 && code <= 82)) return SYM_W_RAIN; 
    if ((code >= 71 && code <= 77) || code == 85 || code == 86) return SYM_W_SNOW; 
    if (code >= 95) return SYM_W_STORM; 
    return SYM_W_SUN; 
}

void encode_url_spaces(const char *src, char *dest) {
    while (*src) {
        if (*src == ' ') { *dest++ = '%'; *dest++ = '2'; *dest++ = '0'; }
        else { *dest++ = *src; }
        src++;
    }
    *dest = '\0';
}


// ==========================================================
// 4. TASKI GŁÓWNE (FreeRTOS)
// ==========================================================
void nrf_receiver_task(void *pvParameters) {
    SensorData localData = {0};
    while(1) {
        if (xSpiMutex && xSemaphoreTake(xSpiMutex, pdMS_TO_TICKS(100))) {
            if (nrf_receive_data(nrf_handle, &localData)) {
                xQueueOverwrite(xSensorQueue, &localData);
            }
            xSemaphoreGive(xSpiMutex);
        }
        vTaskDelay(pdMS_TO_TICKS(500));
    }
}

void collect_time_task(void *pvParameters) {
    ESP_LOGI("TIME", "Zadanie czasu uruchomione");
    char saved_ssid[33] = {0};
    char saved_pass[64] = {0};
    static bool sntp_initialized = false; 

    while(1) {
        if (load_wifi_credentials(saved_ssid, saved_pass, sizeof(saved_pass))) {
            wifi_ap_record_t ap_info;
            bool connected = (esp_wifi_sta_get_ap_info(&ap_info) == ESP_OK);
            
            if (!connected) {
                ESP_LOGW("TIME", "Brak polaczenia. Inicjuje WiFi...");
                is_wifi_connecting = true; 
                connected = wifi_connect_station(saved_ssid, saved_pass);
                is_wifi_connecting = false;
            }
            
            if (connected) { 
                if (!sntp_initialized) {
                    ESP_LOGI("TIME", "Pierwsza synchronizacja czasu SNTP...");
                    sntp_init_module(); 
                    setenv("TZ", "CET-1CEST,M3.5.0,M10.5.0/3", 1); 
                    tzset();
                    wait_for_time_sync(); 
                    sntp_initialized = true;
                }
                vTaskDelay(pdMS_TO_TICKS(3600 * 1000)); 
            } else { 
                vTaskDelay(pdMS_TO_TICKS(30000)); 
            }
        } else {
            vTaskDelay(pdMS_TO_TICKS(10000)); 
        }
    }
}

void fetch_weather_task(void *pvParameters) {
    const char* pl_days[] = {"NIE", "PON", "WTO", "ŚRO", "CZW", "PIĄ", "SOB"};
    int weather_timer = 1800; 

    while(1) {
        time_t now; struct tm timeinfo;
        time(&now); localtime_r(&now, &timeinfo);
        bool is_time_synced = (timeinfo.tm_year > (2020 - 1900));

        wifi_ap_record_t ap_info;
        bool is_wifi_connected = (esp_wifi_sta_get_ap_info(&ap_info) == ESP_OK);

        if (is_wifi_connected && is_time_synced && (force_weather_update || weather_timer >= 1800)) {
            ESP_LOGI(TAG, "Pobieranie najnowszej pogody dla: %s", current_city);
            force_weather_update = false; 
            weather_timer = 0;            
            
            char encoded_city[128];
            encode_url_spaces(current_city, encoded_city);

            char geo_url[256];
            snprintf(geo_url, sizeof(geo_url), "http://geocoding-api.open-meteo.com/v1/search?name=%s&count=1&language=pl&format=json", encoded_city);

            esp_http_client_config_t config = { .url = geo_url, .method = HTTP_METHOD_GET, .timeout_ms = 5000 };
            esp_http_client_handle_t client = esp_http_client_init(&config);
            esp_err_t err = esp_http_client_open(client, 0);

            float lat = 200.0, lon = 200.0; 

            if (err == ESP_OK) {
                esp_http_client_fetch_headers(client);
                char *buffer = malloc(4096); 
                if (buffer) {
                    int total_read = 0;
                    while (total_read < 4095) {
                        int read_len = esp_http_client_read(client, buffer + total_read, 4095 - total_read);
                        if (read_len <= 0) break;
                        total_read += read_len;
                        vTaskDelay(pdMS_TO_TICKS(1));
                    }
                    buffer[total_read] = 0;
                    
                    cJSON *root = cJSON_Parse(buffer);
                    if (root) {
                        cJSON *results = cJSON_GetObjectItem(root, "results");
                        if (cJSON_IsArray(results) && cJSON_GetArraySize(results) > 0) {
                            cJSON *first_result = cJSON_GetArrayItem(results, 0);
                            lat = cJSON_GetObjectItem(first_result, "latitude")->valuedouble;
                            lon = cJSON_GetObjectItem(first_result, "longitude")->valuedouble;
                        }
                        cJSON_Delete(root);
                    }
                    free(buffer);
                }
            }
            esp_http_client_cleanup(client);

            if (lat != 200.0) {
                char weather_url[256];
                snprintf(weather_url, sizeof(weather_url), "http://api.open-meteo.com/v1/forecast?latitude=%.2f&longitude=%.2f&daily=weather_code,temperature_2m_max,temperature_2m_min&timezone=Europe%%2FWarsaw", lat, lon);
                
                esp_http_client_config_t w_config = { .url = weather_url, .method = HTTP_METHOD_GET, .timeout_ms = 5000 };
                esp_http_client_handle_t w_client = esp_http_client_init(&w_config);
                err = esp_http_client_open(w_client, 0);

                if (err == ESP_OK) {
                    esp_http_client_fetch_headers(w_client);
                    char *w_buffer = malloc(4096); 
                    if (w_buffer) {
                        int total_read = 0;
                        while (total_read < 4095) {
                            int read_len = esp_http_client_read(w_client, w_buffer + total_read, 4095 - total_read);
                            if (read_len <= 0) break;
                            total_read += read_len;
                        }
                        w_buffer[total_read] = 0;

                        cJSON *root = cJSON_Parse(w_buffer);
                        if (root) {
                            cJSON *daily = cJSON_GetObjectItem(root, "daily");
                            if (daily) {
                                cJSON *w_codes = cJSON_GetObjectItem(daily, "weather_code");
                                cJSON *t_max = cJSON_GetObjectItem(daily, "temperature_2m_max");
                                cJSON *t_min = cJSON_GetObjectItem(daily, "temperature_2m_min");

                                if (w_codes && t_max && t_min) {
                                    int today_wday = timeinfo.tm_wday; 
                                    lvgl_port_lock(-1);
                                    for(int i = 0; i < 7; i++) {
                                        cJSON *code_item = cJSON_GetArrayItem(w_codes, i);
                                        cJSON *max_item = cJSON_GetArrayItem(t_max, i);
                                        cJSON *min_item = cJSON_GetArrayItem(t_min, i);

                                        if (code_item && max_item && min_item) {
                                            lv_label_set_text(forecast_icon_labels[i], get_weather_icon(code_item->valueint));
                                            lv_label_set_text_fmt(forecast_temp_labels[i], "%d°C\n%d°C", (int)max_item->valuedouble, (int)min_item->valuedouble);
                                            
                                            if (i == 0) lv_label_set_text(forecast_day_labels[i], "DZIŚ");
                                            else if (i == 1) lv_label_set_text(forecast_day_labels[i], "JUTRO");
                                            else lv_label_set_text(forecast_day_labels[i], pl_days[(today_wday + i) % 7]);
                                        }
                                    }
                                    lvgl_port_unlock();
                                }
                            }
                            cJSON_Delete(root);
                        }
                        free(w_buffer);
                    }
                }
                esp_http_client_cleanup(w_client);
            }
        }
        weather_timer++;
        vTaskDelay(pdMS_TO_TICKS(2000));
    }
}

void update_ui_task(void *pvParameters) {
    SensorData receivedData = {0};
    char buf[64];
    time_t now; 
    struct tm timeinfo;
    int start_delay_counter = 5; 
    int chart_update_counter = 590; 
    int last_day = -1; 
    bool first_chart_point = true; 
    
    while(1) {
        xQueueReceive(xSensorQueue, &receivedData, 0);
        uint8_t battery_level = get_battery_level(receivedData.battery_mv);
        
        time(&now);
        localtime_r(&now, &timeinfo);
        
        wifi_ap_record_t ap_info;
        esp_err_t res = esp_wifi_sta_get_ap_info(&ap_info);

        lvgl_port_lock(-1); 

        sprintf(buf, "%.2f °C", receivedData.temp_hundredths / 100.0f);
        lv_label_set_text(lbl_temp, buf); 
        sprintf(buf, "%.2f %%", receivedData.hum_x1024 / 1024.0f);
        lv_label_set_text(lbl_hum, buf);
        sprintf(buf, "%.0f hPa", receivedData.pressure_pa / 100.0f);
        lv_label_set_text(lbl_press, buf);

        if (timeinfo.tm_year > (2020 - 1900)) {
            if (last_day == -1) last_day = timeinfo.tm_mday;
            if (last_day != timeinfo.tm_mday) {
                lv_chart_set_all_value(chart_temp, ser_temp, LV_CHART_POINT_NONE);
                lv_chart_set_all_value(chart_hum, ser_hum, LV_CHART_POINT_NONE);
                lv_chart_set_all_value(chart_press, ser_press, LV_CHART_POINT_NONE);
                last_day = timeinfo.tm_mday;
                first_chart_point = true; 
            }
        }

        chart_update_counter++;
        if (chart_update_counter >= 1800) {  
            if (ser_temp != NULL && receivedData.pressure_pa > 0 && timeinfo.tm_year > (2020 - 1900)) {
                chart_update_counter = 0; 
                int32_t t = receivedData.temp_hundredths / 100;
                int32_t h = receivedData.hum_x1024 / 1024;
                int32_t p = receivedData.pressure_pa / 100;

                if (t > 80) t = 80; else if (t < -40) t = -40;
                if (h > 100) h = 100; else if (h < 0) h = 0;
                if (p > 1200) p = 1200; else if (p < 800) p = 800;

                uint16_t point_index = (timeinfo.tm_hour * 4) + (timeinfo.tm_min / 15);

                if (point_index < 96) {
                    lv_chart_set_value_by_id(chart_temp, ser_temp, point_index, t);
                    lv_chart_set_value_by_id(chart_hum, ser_hum, point_index, h);
                    lv_chart_set_value_by_id(chart_press, ser_press, point_index, p);
                    
                    if (first_chart_point && point_index > 0) {
                        lv_chart_set_value_by_id(chart_temp, ser_temp, point_index - 1, t);
                        lv_chart_set_value_by_id(chart_hum, ser_hum, point_index - 1, h);
                        lv_chart_set_value_by_id(chart_press, ser_press, point_index - 1, p);
                        first_chart_point = false; 
                    }
                }
            } else if (receivedData.pressure_pa == 0) {
                chart_update_counter = 1798; 
            }
        }
        
        // Zmiana ikon baterii -> (Używamy zdefiniowanych wcześniej makr, zadeklarowanych np. w ui.h, ale my wrzuciliśmy to do pliku main żeby łatwiej sterować).
        // (Ponieważ symboli używamy tylko tutaj, a zostały w ui.c, dla bezpieczeństwa wysyłamy poprawne wywołania do ui.c lub odświeżamy z własnych makr).
        // W ui.c mamy: #define MY_SYM_BAT_100  "\xEF\x89\x80"
        // Jeśli kompilator zgłosi brak makra, przenieś to powiązanie do ui.h. Aby uniknąć tego błędu, dodam te makra tutaj:
        #define LOCAL_SYM_BAT_100  "\xEF\x89\x80" 
        #define LOCAL_SYM_BAT_50   "\xEF\x89\x82" 
        #define LOCAL_SYM_BAT_0    "\xEF\x89\x84" 

        if (battery_level > 75) {
            lv_label_set_text(icon_battery, LOCAL_SYM_BAT_100);
            lv_obj_set_style_text_color(icon_battery, lv_palette_main(LV_PALETTE_GREEN), 0);
        } else if (battery_level > 25) {
            lv_label_set_text(icon_battery, LOCAL_SYM_BAT_50);
            lv_obj_set_style_text_color(icon_battery, lv_palette_main(LV_PALETTE_YELLOW), 0);
        } else {
            lv_label_set_text(icon_battery, LOCAL_SYM_BAT_0);
            lv_obj_set_style_text_color(icon_battery, lv_palette_main(LV_PALETTE_RED), 0);
        }

        if (timeinfo.tm_year > (2020 - 1900)) {
            sprintf(buf, "%02d.%02d.%04d", timeinfo.tm_mday, timeinfo.tm_mon + 1, timeinfo.tm_year + 1900);
            lv_label_set_text(lbl_date, buf);
            sprintf(buf, "%02d:%02d:%02d", timeinfo.tm_hour, timeinfo.tm_min, timeinfo.tm_sec);
            lv_label_set_text(lbl_time, buf);
        }

        if (start_delay_counter > 0) {
            start_delay_counter--;
        } else {
            if (is_wifi_connecting) {
                update_wifi_icon(0, false); 
            } else {
                update_wifi_icon(ap_info.rssi, (res == ESP_OK));
            }
        }

        lvgl_port_unlock(); 
        vTaskDelay(pdMS_TO_TICKS(500)); 
    }
}
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
void app_main(void) {
    ESP_LOGI(TAG, "Start stacji pogodowej z LVGL...");

    esp_err_t ret = nvs_flash_init();
    if (ret == ESP_ERR_NVS_NO_FREE_PAGES || ret == ESP_ERR_NVS_NEW_VERSION_FOUND) {
        ESP_ERROR_CHECK(nvs_flash_erase());
        ret = nvs_flash_init();
    }
    ESP_ERROR_CHECK(ret);

    load_brightness_settings();
    load_location_settings();

    // 1. Inicjalizacja sprzętu
    xSpiMutex = xSemaphoreCreateMutex();
    xSensorQueue = xQueueCreate(1, sizeof(SensorData));
    
    gpio_init();
    spi_init();
    nrf_init(&nrf_handle);
    backlight_pwm_init();
    lcd_init();
    lcd_touch_init(VSPI_HOST);

    // 2. Rysowanie początkowego interfejsu z modułu ui.c
    lvgl_port_lock(-1);
    init_button_styles(); 
    create_weather_ui();
    create_settings_ui();
    create_graph_screen();
    create_weather_info_screen();
    lv_scr_load(main_screen); 
    lvgl_port_unlock();
    
    // 3. Startowanie zadań FreeRTOS
    xTaskCreate(nrf_receiver_task, "NRF_TASK", 4096, NULL, 4, NULL);
    xTaskCreate(collect_time_task, "TIME_TASK", 8192, NULL, 4, NULL); 
    xTaskCreate(update_ui_task, "GUI_UPDATE_TASK", 8192, NULL, 5, NULL);
    xTaskCreate(night_mode_task, "NIGHT_MODE_TASK", 4096, NULL, 5, NULL);
    xTaskCreate(fetch_weather_task, "FETCH_WEATHER", 8192, NULL, 4, NULL);

    ESP_LOGI(TAG, "System dziala!");
    
    while(1) {
        vTaskDelay(pdMS_TO_TICKS(1000));
    }
}

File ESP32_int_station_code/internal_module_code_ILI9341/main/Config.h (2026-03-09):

#pragma once
#define BUTTON_1 GPIO_NUM_4
#define BUTTON_2 GPIO_NUM_16

#define LED1 GPIO_NUM_36
#define LED2 GPIO_NUM_39

// SPI Pins
#define SPI_MISO GPIO_NUM_19
#define SPI_MOSI GPIO_NUM_23
#define SPI_SCLK GPIO_NUM_18

// NRF Pins
#define NRF_CE_PIN GPIO_NUM_17
#define NRF_CSN_PIN GPIO_NUM_22
//NRF Settings
#define RX_ADDRESS_VAL {'A', 'T', '4', '1', '4'}
#define Channel 76
#define NRF_SPEED 0x07 //2Mbps, 0dBm

// --- STRUKTURA DANYCH (14 bajtów) ---
typedef struct __attribute__((packed)) {
    int32_t temp_hundredths;
    uint32_t pressure_pa;
    uint32_t hum_x1024;
    uint16_t battery_mv;
} SensorData;

// LCD Pins
#define CS_PIN GPIO_NUM_21
#define DC_PIN GPIO_NUM_26
#define RESET_PIN GPIO_NUM_25
#define BL_PIN GPIO_NUM_27
//LCD Settings
#define LCD_TYPE 0x7789 //lub 0x9341 0x7789
#define LCD_WIDTH  320
#define LCD_HEIGHT 240
#define LCD_ORIENTATION_1 0x36 // Portrait  //dla ili9341 0x36
#define LCD_ORIENTATION_2 0xE8 // Landscape //dla ili9341 0xA8 0xE8
//Optional LCD
#define T_CS GPIO_NUM_14
#define SD_CS GPIO_NUM_2

#define NRF_IRQ GPIO_NUM_34
#define T_IRQ GPIO_NUM_13

// NTC
#define SSID "Internet domowy Lisiak"
#define PASSWORD  "LismaN1410"
#define SNTP_SERVER "pool.ntp.org"

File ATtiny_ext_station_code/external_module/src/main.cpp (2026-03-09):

/*
 * KOMPLETNY PLIK DIAGNOSTYCZNY DLA ATTINY414 + NRF24L01
 * Funkcje: Nadawanie + Wykrywanie Resetu Radia (Brown-out detection)
 */

#include <avr/io.h>
#include <util/delay.h>
#include <avr/interrupt.h>
#include <stdio.h>
#include <string.h>

#include "Config.h"
#include "SPI.h"
#include "NRF24L01.h"
#include "SoftwareI2C.h"
#include "BME280.h"
#include "RTC_sleep.h"

// Makra LED
#define LED_ON()   (LED_PORT.OUTSET = LED_PIN)
#define LED_OFF()  (LED_PORT.OUTCLR = LED_PIN)

// Funkcja pomocnicza do mrugania (ilość razy, czas ms)
void blink_led(uint8_t count, uint16_t ms) {
    for (uint8_t i = 0; i < count; i++) {
        LED_ON();
        for(uint16_t d=0; d<ms; d++) _delay_ms(1);
        LED_OFF();
        for(uint16_t d=0; d<ms; d++) _delay_ms(1);
    }
}

    // --- FUNKCJA DO POMIARU BATERII (VDD) ---
uint16_t measure_battery_mv(void) {
    // 1. Skonfiguruj wewnętrzne źródło odniesienia (VREF) na 1.5V (standard dla ATtiny414)
    VREF.CTRLA = VREF_ADC0REFSEL_1V5_gc;
    
    // 2. Referencja dla ADC to napięcie zasilania (VDD). Preskaler /16.
    ADC0.CTRLC = ADC_PRESC_DIV16_gc | ADC_REFSEL_VDDREF_gc;
    
    // 3. Jako wejście dla ADC wybieramy wewnętrzne napięcie (INTREF)
    ADC0.MUXPOS = ADC_MUXPOS_INTREF_gc;
    
    // 4. Włącz ADC
    ADC0.CTRLA = ADC_ENABLE_bm;
    
    // 5. Odrzuć pierwszy pomiar (zalecane przy starcie ADC i zmianie VREF)
    ADC0.COMMAND = ADC_STCONV_bm;
    while (!(ADC0.INTFLAGS & ADC_RESRDY_bm));
    ADC0.INTFLAGS = ADC_RESRDY_bm; // Czyszczenie flagi
    
    // 6. Właściwy pomiar
    ADC0.COMMAND = ADC_STCONV_bm;
    while (!(ADC0.INTFLAGS & ADC_RESRDY_bm));
    ADC0.INTFLAGS = ADC_RESRDY_bm;
    uint16_t adc_res = ADC0.RES;
    
    // 7. Wyłącz ADC przed pójściem spać, żeby oszczędzać prąd
    ADC0.CTRLA &= ~ADC_ENABLE_bm;
    
    // 8. Obliczenia:
    // Wzór: ADC = (Vref / VDD) * 1024
    // Przekształcamy to do postaci miliwoltów: VDD_mV = (1.5V * 1024 * 1000) / ADC
    // 1500 * 1024 = 1536000
    if (adc_res == 0) return 0;
    return (uint16_t)(1536000UL / adc_res);
}

int main(void) {
    _PROTECTED_WRITE(CLKCTRL.MCLKCTRLB, 0); 

    LED_PORT.DIRSET = LED_PIN; // LED jako wyjście
    LED_OFF();

    SPI_init();
    TWI_Init();
    NRF_init();
    RTC_Init();

    sei();//włączamy globalne przerwania
    
    NRF_set_tx_mode(); //ustawienie nrf jako nadajnik
    
    BME280_Init();
    BME280_ReadCalibration();
    sensor_packet_t pkt;

    while (1) {
        uint8_t data[8];
        BME280_ReadBytes(0xF7, data, 8);

        // ciśnienie (20 bit)
        uint32_t raw_press = ((uint32_t)data[0] << 12) | ((uint32_t)data[1] << 4) | ((uint32_t)data[2] >> 4);

        // temperatura (20 bit)
        uint32_t raw_temp  = ((uint32_t)data[3] << 12) | ((uint32_t)data[4] << 4) | ((uint32_t)data[5] >> 4);

        // wilgotność (16 bit)
        uint32_t raw_hum   = ((uint32_t)data[6] << 8)  | ((uint32_t)data[7]);

        NRF_write_reg(0x00, 0x0A); //na nowo włączamy zasilanie radia na czas transmisji
        _delay_ms(10); //uśpienie potrzebne na uruchomienie się oscylatora układu

        //Tutaj jest przyklzd kompensacji, potem wstawimy prawdziwe funkcje
        
        pkt.temp_hundredths = BME280_Compensate_T(raw_temp); //0.01°C
        pkt.pressure_pa    = BME280_Compensate_P(raw_press); //Pa
        pkt.hum_x1024      = BME280_Compensate_H(raw_hum);
        pkt.vcc_mv         = measure_battery_mv(); //pomiar napięcia baterii w mV
        
        NRF_write_reg(0x07, 0x70); //wyczyszczenie flag statusu

        NRF_send_packet(&pkt); //wyślij dane
        //blink_led(3, 100); //sygnalizacja wysłania danych
        _delay_ms(10); //odkomentowac w przypaku zakomentowania blink_led();
        NRF_write_reg(0x00,0x00); //całkowite uśpienie radia nrf na czas braku transmisji

        //_delay_ms(5000); //uśpienie tylko w trakcie testu komunikacji
        //zamiast delay go to sleep
        GoToSleep(); 

    }
}

// Obsługa przerwania - budzik zadzwonił
ISR(RTC_PIT_vect) {
    // Wyczyść flagę przerwania, żeby nie wpaść w pętlę
    RTC.PITINTFLAGS = RTC_PI_bm;
}

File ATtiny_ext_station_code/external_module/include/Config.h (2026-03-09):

#include <avr/io.h>
#define F_CPU 20000000UL // 20 MHz

#define SLEEP_SCALER RTC_PERIOD_CYC8192_gc //Co 8 sekund sygnał 
/* inne dzielniki czasu uspania:
    RTC_PERIOD_CYC1024_gc  = 1 sekunda
    RTC_PERIOD_CYC4096_gc  = 4 sekundy
    RTC_PERIOD_CYC8192_gc  = 8 sekund
    RTC_PERIOD_CYC16384_gc = 16 sekund
    RTC_PERIOD_CYC32768_gc = 32 sekundy

*/

/*w celu optymalizacji zużycia enrgii zalecamy zakomentować 
blink_led(3, 100); //sygnalizacja wysłania danych w pliku main.cpp
*/

#define LED_PORT  PORTA
#define LED_PIN   PIN7_bm //lub PIN6_bm w zależności od płytki

#define NRF_CE_PIN PIN5_bm
#define NRF_CSN_PIN PIN4_bm

#define I2C_PORT    PORTB
#define SCL_PIN     PIN0_bm  // Jeśli w teście działało odwrotnie, zamień na PIN1_bm
#define SDA_PIN     PIN1_bm  // Jeśli w teście działało odwrotnie, zamień na PIN0_bm

#define SPI_PORT PORTA
#define MOSI_PIN PIN1_bm
#define MISO_PIN PIN2_bm
#define SCK_PIN PIN3_bm

#define Channel 76
#define NRF_SPEED 0x07 //2Mbps, 0dBm
#define SPI_SEND_ADDRESS() do { \
    SPI_transfer('A'); \
    SPI_transfer('T'); \
    SPI_transfer('4'); \
    SPI_transfer('1'); \
    SPI_transfer('4'); \
} while(0) //wysyła 5 bajtów adresu

#define BME280_ADDR 0x76 //lub 0x77 zaleznie od plytki

typedef struct __attribute__((packed)) {//to jest struktura 14 bajtowa, nrf może przyjąc 32, dzieki struktorze packet wyslemy cale 12 bajtow za jednym zamachem
    int32_t temp_hundredths;
    uint32_t pressure_pa;
    uint32_t hum_x1024;
    uint16_t vcc_mv; // napięcie baterii w mV
} sensor_packet_t; //musi być taka sama na odbiorniku (ESP32)

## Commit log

2025-11-19 stworzenie folderow do projektow pcb i dodanie plikow
    [Stacja_pogody_SD.kicad_pcb, Stacja_pogody_SD.kicad_sch, Wireless Radio Transmitter and Receiver nRF24L01.STEP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]
2025-11-19 datasheet esp32
2025-11-25 poprawa plytki wew i zew
    [Stacja_pogody_SD.kicad_pcb, Stacja_pogody_SD.kicad_sch, stacja_pogody_moduł_wew.kicad_pcb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]
2025-11-25 poprawa gerberow wew
    [stacja_pogody_moduł_wew.GBL, stacja_pogody_moduł_wew.GBO, stacja_pogody_moduł_wew.GBP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]
2025-11-25 dodanie uart_init
2025-11-26 skonczona plytka dla plytki zew
    [Stacja_pogody_SD.GBL, Stacja_pogody_SD.GBO, Stacja_pogody_SD.GBP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]
2025-11-26 powiekszyc sciezki do 0.2mm w wew
    [stacja_pogody_moduł_wew.kicad_pcb, stacja_pogody_moduł_wew.kicad_sch]
2025-11-26 dokonczona plytka wew
    [stacja_pogody_moduł_wew.GBL, stacja_pogody_moduł_wew.GBO, stacja_pogody_moduł_wew.GBP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]
2025-11-26 skonczona plytka wewnetrzna
    [stacja_pogody_moduł_wew.GBL, stacja_pogody_moduł_wew.GBO, stacja_pogody_moduł_wew.GBP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]
2025-11-29 Dodana obsluga I2C oraz czujnika BME
2025-11-30 Dodana obsluga SPI i NRF, przy dobrych wiatrach moze juz zadzialac caly czujnik
2025-12-01 inicjalizacja SPI
2025-12-01 SPI dla NRF niby zrobione
2025-12-02 poprawa footprintu usb
    [stacja_pogody_moduł_wew.GBL, stacja_pogody_moduł_wew.GBO, stacja_pogody_moduł_wew.GBP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]
2025-12-06 Program na obslugujacy nrf, lcd
    [partitions.csv]
2025-12-13 Kod do ATtiny całkowicie gotowy. Do zrobienia obsługa wyświetlacza, gpio i uart jak bedzie ten wewnętrzny transiver
2025-12-13 usuniecie starego
    [partitions.csv]
2025-12-14 Działający wyświetlacz
    [partitions.csv]
2026-02-02 Zrobiona wersja testowa z podwojnym buforowaniem.
    [partitions.csv]
2026-02-04 Kompatybilny kod internal-module-podwojne_buforowanie dla st oraz ili, zmiana wyswietlacza w pliku Config.h
    [partitions.csv]
2026-02-08 ext case prototype
    [Case_ext.FCStd]
2026-02-08 ext_station case
    [Case_ext.FCStd, Case_ext_top.FCStd]
2026-02-08 ext_case update
    [Case_ext.3mf, Case_ext.step, Case_ext.stl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]
2026-02-08 case update
    [Case_ext.3mf, Case_ext.FCStd, Case_ext.step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]
2026-02-23 Recode graphic driver to LVGL
    [partitions.csv]
2026-02-24 deviding code for ST7789 and ILI graphic driver
    [partitions.csv]
2026-02-24 ext station battery status + settings button + touch
2026-03-04 wifi search added with refresh button and power signal symbol
2026-03-09 battery status in mV
2026-03-14 added code for ili9341 graphic driver
    [Interial_station_bottom_case-BodyHole001.step, Interial_station_bottom_case.FCStd, Interial_station_bottom_case.stl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]
2026-03-15 photos of project
    [Stacja_pogody_SD.kicad_sch, case_ext_merged.FCStd, stacja_pogody_moduł_wew.kicad_sch]
2026-03-15 Add README for RF Meteo Station project
    Added a comprehensive README for the RF Meteo Station project, detailing PCB design, enclosure design, code architecture, build instructions, and final results.
2026-03-15 Revise images and schematic references in README
    Updated images and schematic links in README.
2026-03-15 case photos
2026-03-15 Update images in README for case models
